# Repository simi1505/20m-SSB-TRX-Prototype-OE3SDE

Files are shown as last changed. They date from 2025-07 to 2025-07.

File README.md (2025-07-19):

# 20m-SSB-TRX-Prototype-OE3SDE
Prototype on a 20m SSB TRX for ham radio by OE3SDE.

## Block Diagram

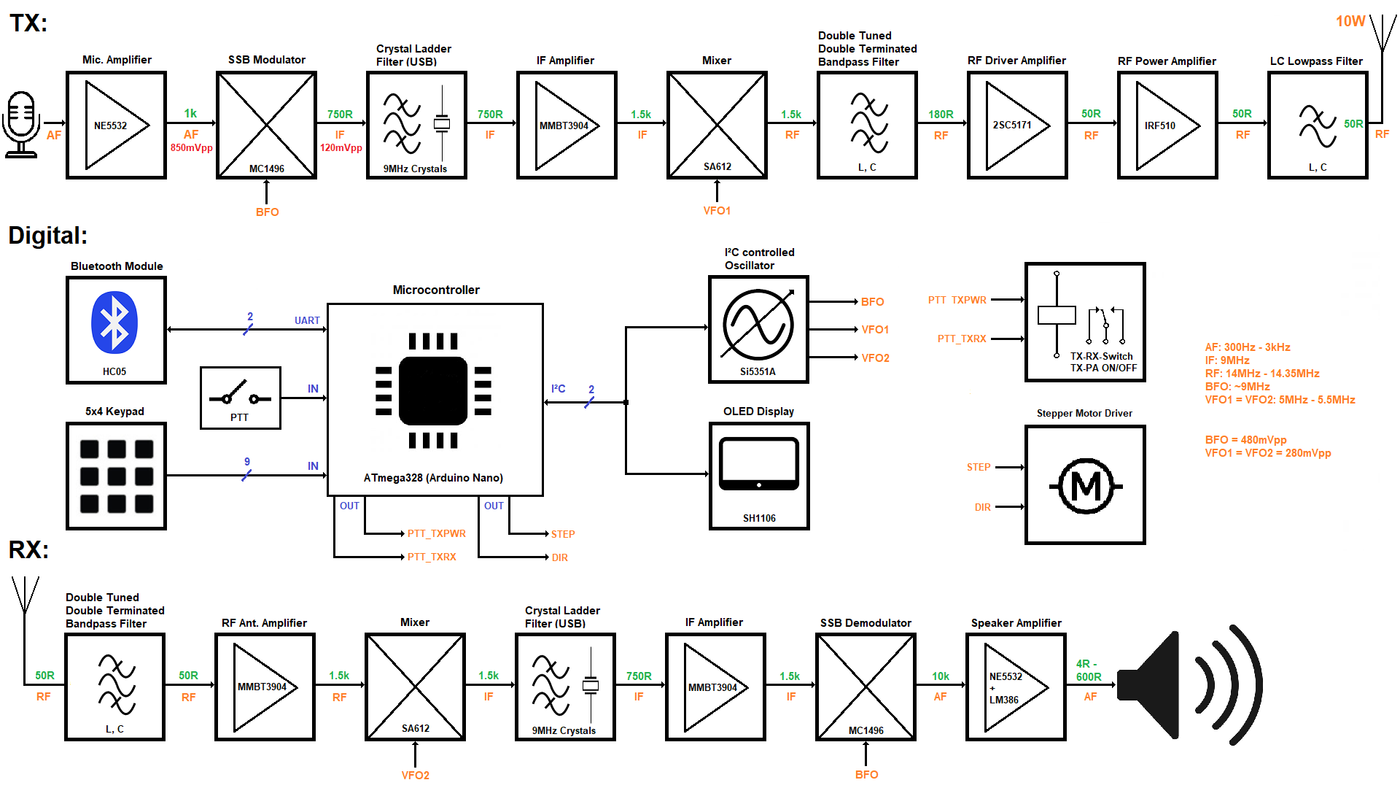
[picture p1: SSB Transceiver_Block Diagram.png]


**Figure 1**: Block diagram of 20m SSB TRX.

## Frequency Spectrum

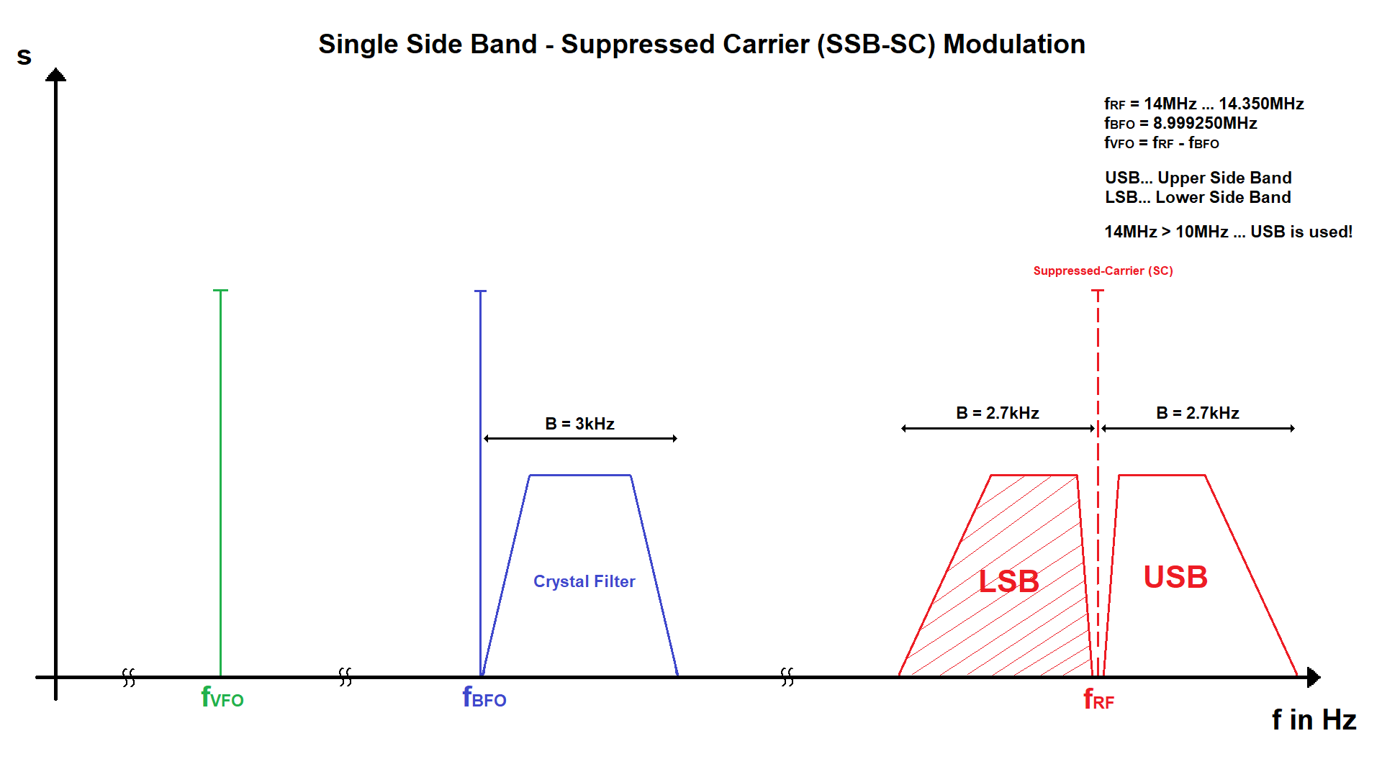
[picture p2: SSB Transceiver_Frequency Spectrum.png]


**Figure 2**: Frequency spectrum of 20m SSB TRX.

## Result

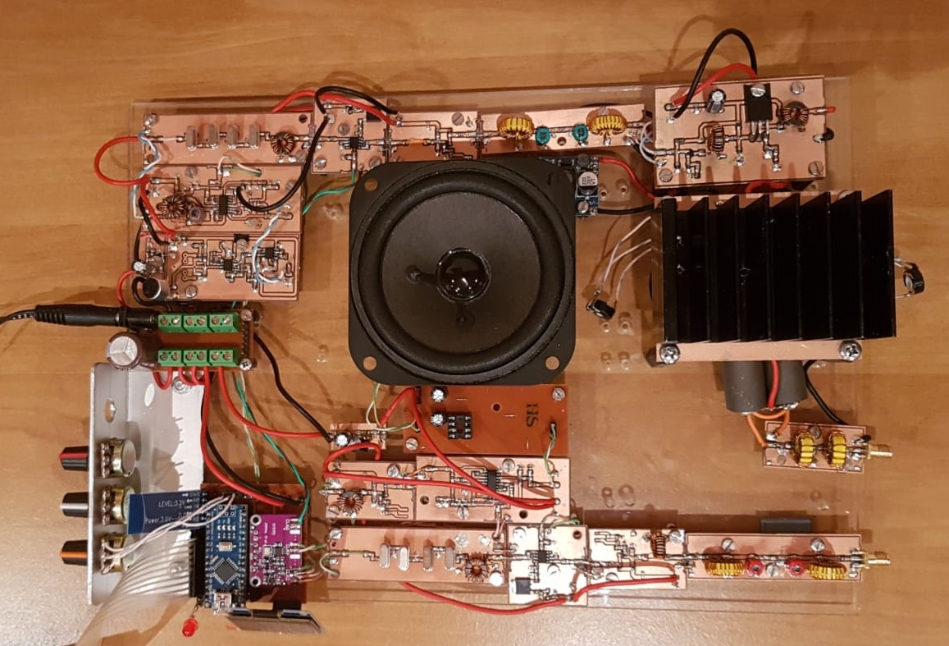
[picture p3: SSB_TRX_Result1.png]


**Figure 3**: Result of 20m SSB TRX prototype.

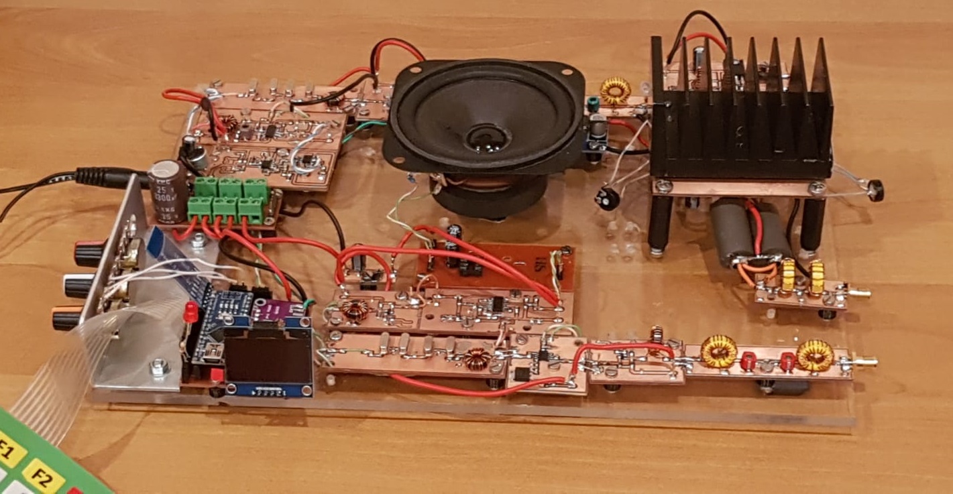
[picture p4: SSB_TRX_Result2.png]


**Figure 4**: Result of 20m SSB TRX prototype.

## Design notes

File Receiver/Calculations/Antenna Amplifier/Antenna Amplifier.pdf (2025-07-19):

Antenna Amplifier | SSB-Transceiver

given: UB≔12V, IC≔0.0033A, βDC≔210 @ 5mA, UBE≔0.6V, f≔14000000Hz
UT≔0.028V @ 5mA, R ≔ | Ohm, | Hz L | 1500 | fT≔300000000

1.) Calculate Bias Voltages:

URC≔0.413 ⋅UB =4.956 V

URE≔0.1 ⋅UB =1.2 V

UCE≔UB −URE −URC =5.844 V

2.) Calculate RE :

RE≔――=

URE
IC

363.636 Ohm = 360Ohm

3.) Calculate IB & I : q

IB≔――=

IC

βDC

0.0000157 A = 15.7uA | Iq≔10 ⋅ IB =0.000157 A = 157uA

4.) Calculate Bias Resistors:

R1≔―――――=

UB −URE −UBE
Iq+IB

59008.264 Ohm = 62k

R2≔――――=

URE +UBE
Iq

11454.545Ohm = 12k

5.) Calculate Z : IN

RE1≔300 Ohm RE2≔100 Ohm variable --> 56...1056Ohm

rE≔――=

UT
IC

8.485 Ohm βAC≔―=

fT
f

21.429 REV≔――――

RE1 ⋅RE2

RE1+RE2

ZIN≔―――――――――=

1

―+ +

1
R1

―1
R2

―――1 ―― βAC ⋅ ⎛⎝rE +REV⎞
⎠

1507.768 Ohm ZIN = 1061...3300Ohm

ZIN = 1.5k @ RE2 = 100Ohm --> VU = 9 (Simulation) --> perfect conditions

RE1 and RE2 are calculated in 9.). | clear ⎛⎝RE1 ,RE2 ,REV⎞ ⎠

Non-Commercial Use Only

Page 1 of 3

6.) Calculate Input Transformer:

ZP≔50 Ohm | ZS≔ZIN =1507.768Ohm
| --> Guideline: 4T:22T @ FT37-43 Toroid Core --> LP≔5.6 ⋅ 10 H @ FT37-43 Toroid Core ⁻⁶ --> LS≔169.4 ⋅ 10 H @ FT37-43 Toroid Core ⁻⁶
ü≔ | =
―

ZS
ZP

5.491

üdB≔10 ⋅log((ü))=7.397 | dB --> 7.397dB gain!
ZS≔ZP ⋅ | =

⎛
⎜

⎝―22
4

⎞
⎟
⎠

2
1512.5 Ohm

Requirement:

XLP≔2 ⋅π⋅ f ⋅LP=492.602 | Ohm > 9 ⋅ZP=450 Ohm --> correct!
XLS≔2 ⋅π⋅ f ⋅LS=14901.202 Ohm > 9 ⋅Z = | Ohm --> correct! IN 13569.912

7.) Calculate ZOUT :

RC≔――=

URC
IC

1501.818 Ohm

8.) Calculate Output Transformer:

No Transformer needed --> input impedance of SA612 equals 1.5k

Page 2 of 3

9.) Calculate VU & REV :

Split up RE in two parallel resistors RE1 & RE2 --> precise VU

REV＝――――

RE1 ⋅RE2

RE1+RE2

VU≔10 :

VU＝―――――→

RC

REV

solve ,REV
150.18181818181818 Ohm = 150Ohm

VU≔5 :

VU＝―――――→

RC

REV

solve ,REV
300.36363636363636 Ohm = 300Ohm

Simulation: RE1＝300Ohm --> IC = 3.3mA, RE2= 56...1056Ohm -->VU = 13...3 @ RL

10.) Calculate Lower Cut-Off Frequency:

CIN≔0.0000001 F = 100nF | COUT≔CIN | CE≔C ⋅ IN 10 | RE1≔200

rBE≔――=

UT
IB

1781.818 Ohm

fGLI≔―――――――=

1
⎛⎝2 ⋅π⋅ ⎛ | ⋅ ⎝ZP ⋅ rBE⎞

⎠ CIN⎞
⎠

17.864 Hz ... Input Cut Off Frequency

fGLO≔――――――――=

1
⎛⎝2 ⋅π⋅ ⎛ | ⋅ ⎝RC +RL

⎞

⎠ COUT⎞
⎠

530.195 Hz ... Output Cut Off Frequency

fGLE≔――――――――――――=

1
⎛⎝2 ⋅π⋅ ⎛ | ⋅ ⎝ZP+rBE +RE1 ⋅ ⎛⎝βDC +1⎞
⎠

⎞
⎠ CE

⎞
⎠

3.615 Hz

... Emitter Cut Off Frequency

The lowest cut off frequency determines the lower cut off frequency of the amplifier!

Page 3 of 3

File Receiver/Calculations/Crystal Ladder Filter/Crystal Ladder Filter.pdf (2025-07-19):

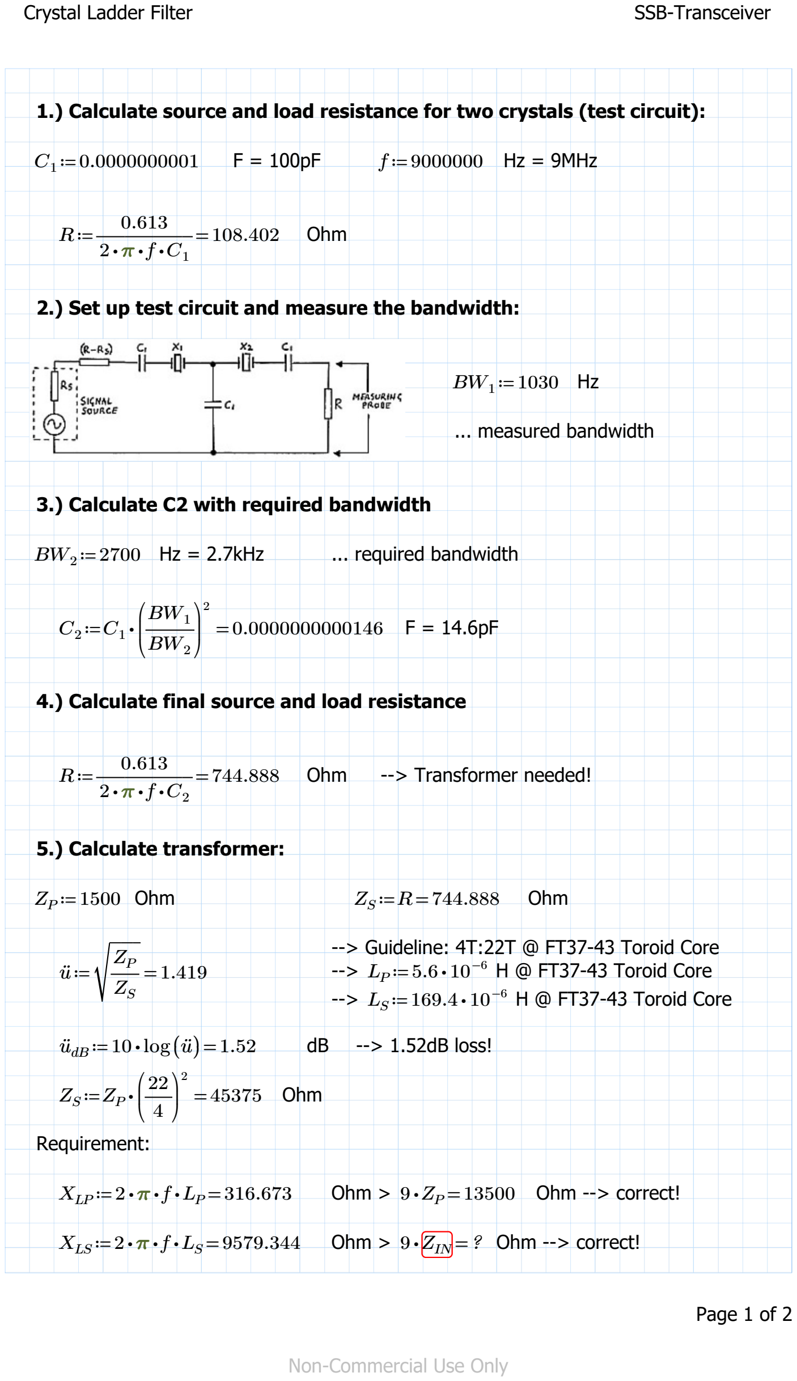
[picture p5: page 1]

Crystal Ladder Filter | SSB-Transceiver

1.) Calculate source and load resistance for two crystals (test circuit):

C1≔0.0000000001 | F = 100pF | f≔9000000 Hz = 9MHz

R≔――――=

0.613
2 ⋅π⋅ f ⋅C1

108.402 Ohm

2.) Set up test circuit and measure the bandwidth:

BW1≔1030 Hz

... measured bandwidth

3.) Calculate C2 with required bandwidth

BW2≔2700 Hz = 2.7kHz ... required bandwidth

C2≔C1

⋅ | =

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
0.0000000000146 F = 14.6pF

4.) Calculate final source and load resistance

R≔――――=

0.613
2 ⋅π⋅ f ⋅C2

744.888 Ohm --> Transformer needed!

5.) Calculate transformer:

ZP≔1500 Ohm | ZS≔R=744.888 | Ohm

--> Guideline: 4T:22T @ FT37-43 Toroid Core --> LP≔5.6 ⋅ 10 H @ FT37-43 Toroid Core ⁻⁶ --> LS≔169.4 ⋅ 10 H @ FT37-43 Toroid Core ⁻⁶

ü≔ =
―

ZP
ZS

1.419

üdB≔10 ⋅log((ü))=1.52 | dB --> 1.52dB loss!
ZS≔ZP ⋅ | =

⎛
⎜

⎝―22
4

⎞
⎟
⎠

2
45375 Ohm

Requirement:

XLP≔2 ⋅π⋅ f ⋅LP=316.673 | Ohm > 9 ⋅ZP=13500 Ohm --> correct!
XLS≔2 ⋅π⋅ f ⋅LS=9579.344 | Ohm > 9 ⋅Z = | Ohm --> correct! IN ?

Non-Commercial Use Only

Page 1 of 2

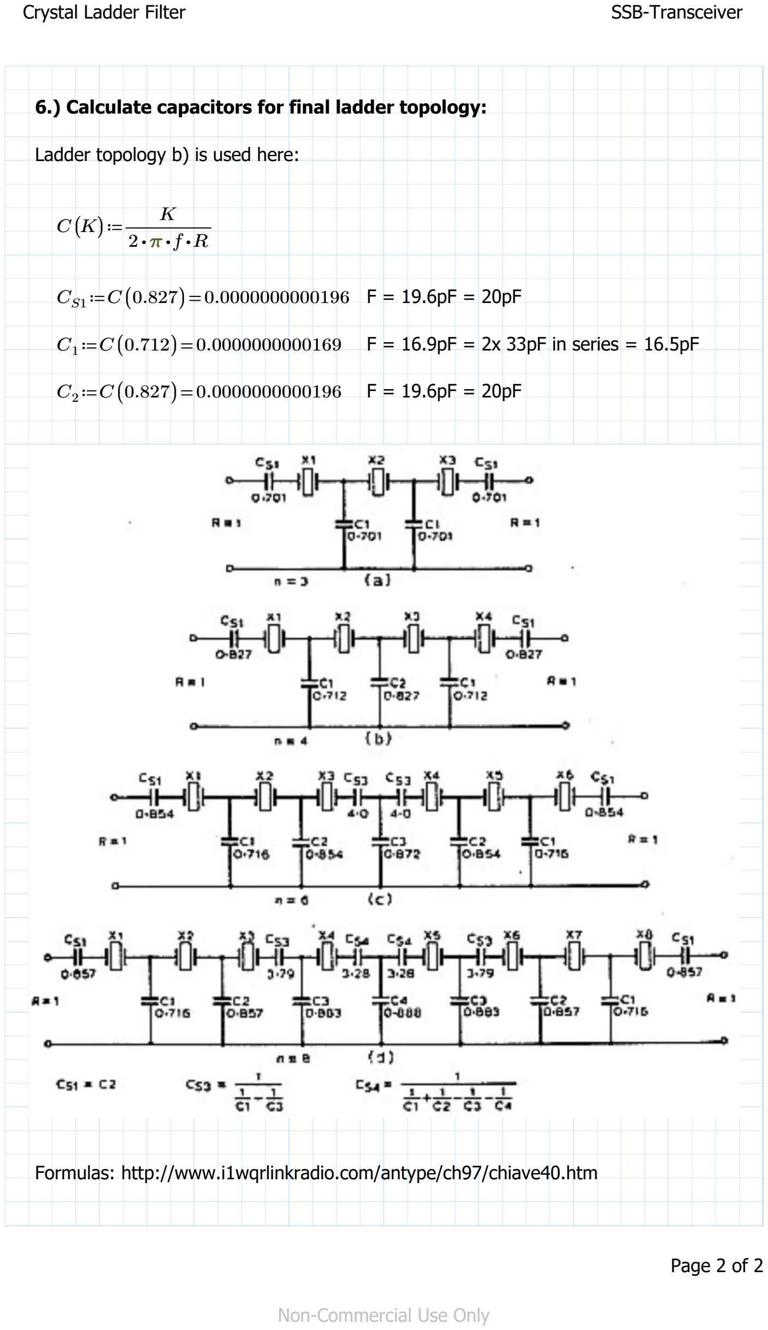
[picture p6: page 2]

Crystal Ladder Filter | SSB-Transceiver

6.) Calculate capacitors for final ladder topology:

Ladder topology b) is used here:

C((K))≔――K ―― 2 ⋅π⋅ f ⋅R

CS1≔C((0.827))=0.0000000000196 F = 19.6pF = 20pF

C1≔C((0.712))=0.0000000000169 F = 16.9pF = 2x 33pF in series = 16.5pF

C2≔C((0.827))=0.0000000000196 F = 19.6pF = 20pF

Formulas: http://www.i1wqrlinkradio.com/antype/ch97/chiave40.htm

Non-Commercial Use Only

Page 2 of 2

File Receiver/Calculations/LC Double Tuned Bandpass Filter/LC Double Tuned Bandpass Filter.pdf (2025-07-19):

LC Double Tuned Bandpass Filters | SSB-Transceiver

Circuit:

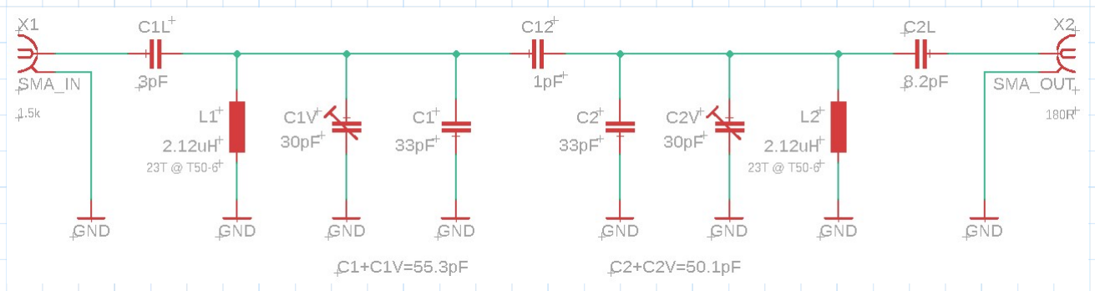
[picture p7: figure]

1.) Define lower and upper cut off frequencies:

f1≔13000000 f2≔15000000

2.) Define inductor core, turns and value (L＝L ＝ ): 1 | L2
L≔2.12 ⋅ 10⁻⁶ | H = 2.12uH --> 23T @ T50-6 Core --> "toroids.info/T50-6.php"
QU≔240 | ... unloaded Q of the resonators

3.) Calculate ω : 0

ω0

... center angular frequency

ω0≔2 ⋅π⋅ f1

⋅f2

=87739907.869 rad/sec

4.) Calculate C : 0

C0

... nodal capacitance

C0≔―――=

1
ω ⋅ 0

### 2 L

0.0000000000613 F = 61.3pF

5.) Calculate Q : L

QL

... loaded filter Q

QL≔―――――=

ω0
2 ⋅π⋅ ⎛⎝f2−f1

⎞
⎠

6.982

Non-Commercial Use Only

Page 1 of 3

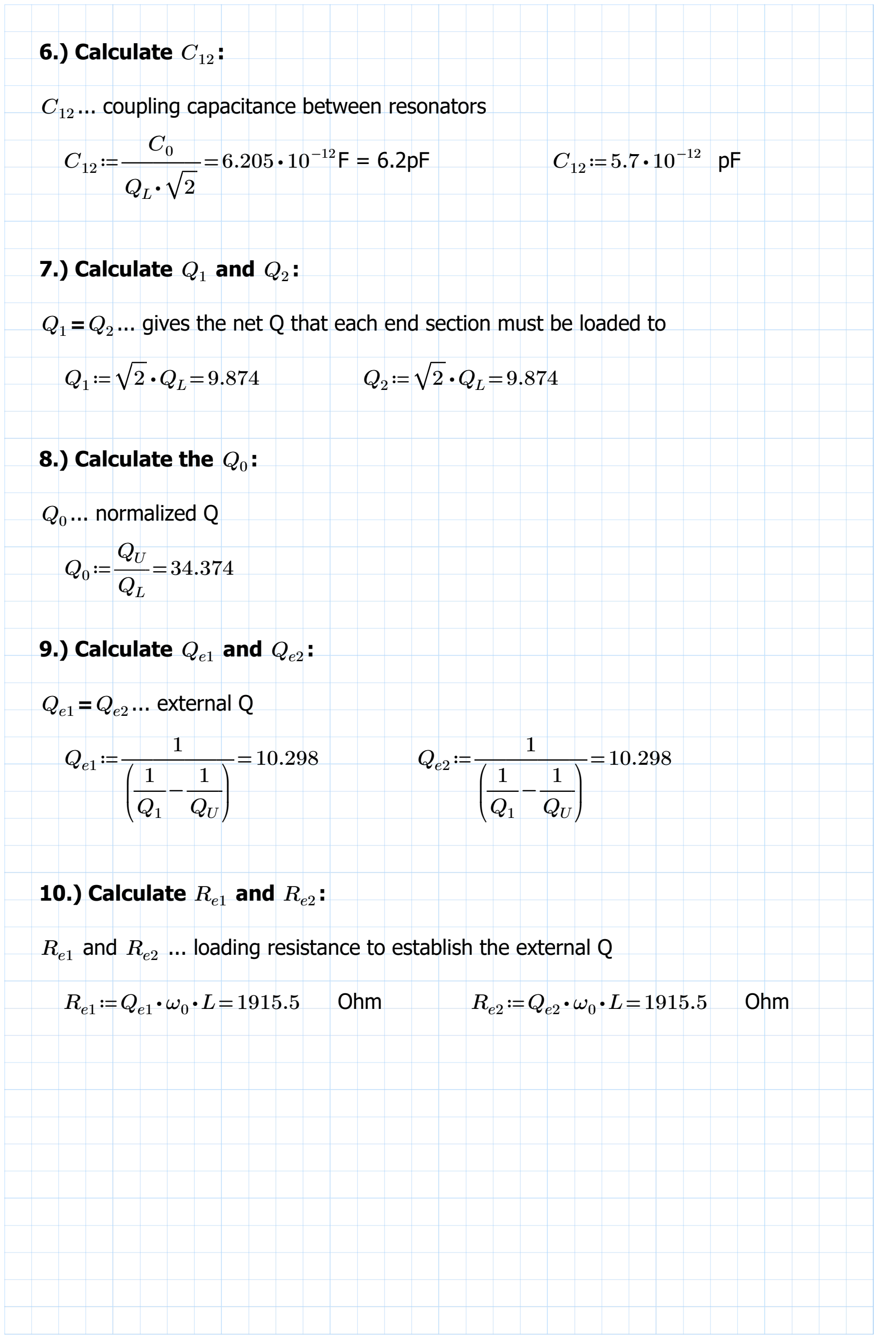
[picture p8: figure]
6.) Calculate C : 12; 7.) Calculate Q and; 8.) Calculate the Q : 0; ... normalized Q; 9.) Calculate Q and; Qe1＝Qe2 ... external Q; 10.) Calculate R and; Ohm

C ... coupling capacitance between resonators 12

6.205 ⋅ 10⁻¹² F = 6.2pF | C12≔5.7 ⋅ 10⁻¹² pF

... gives the net Q that each end section must be loaded to

Re1 and Re2 ... loading resistance to establish the external Q

Page 2 of 3

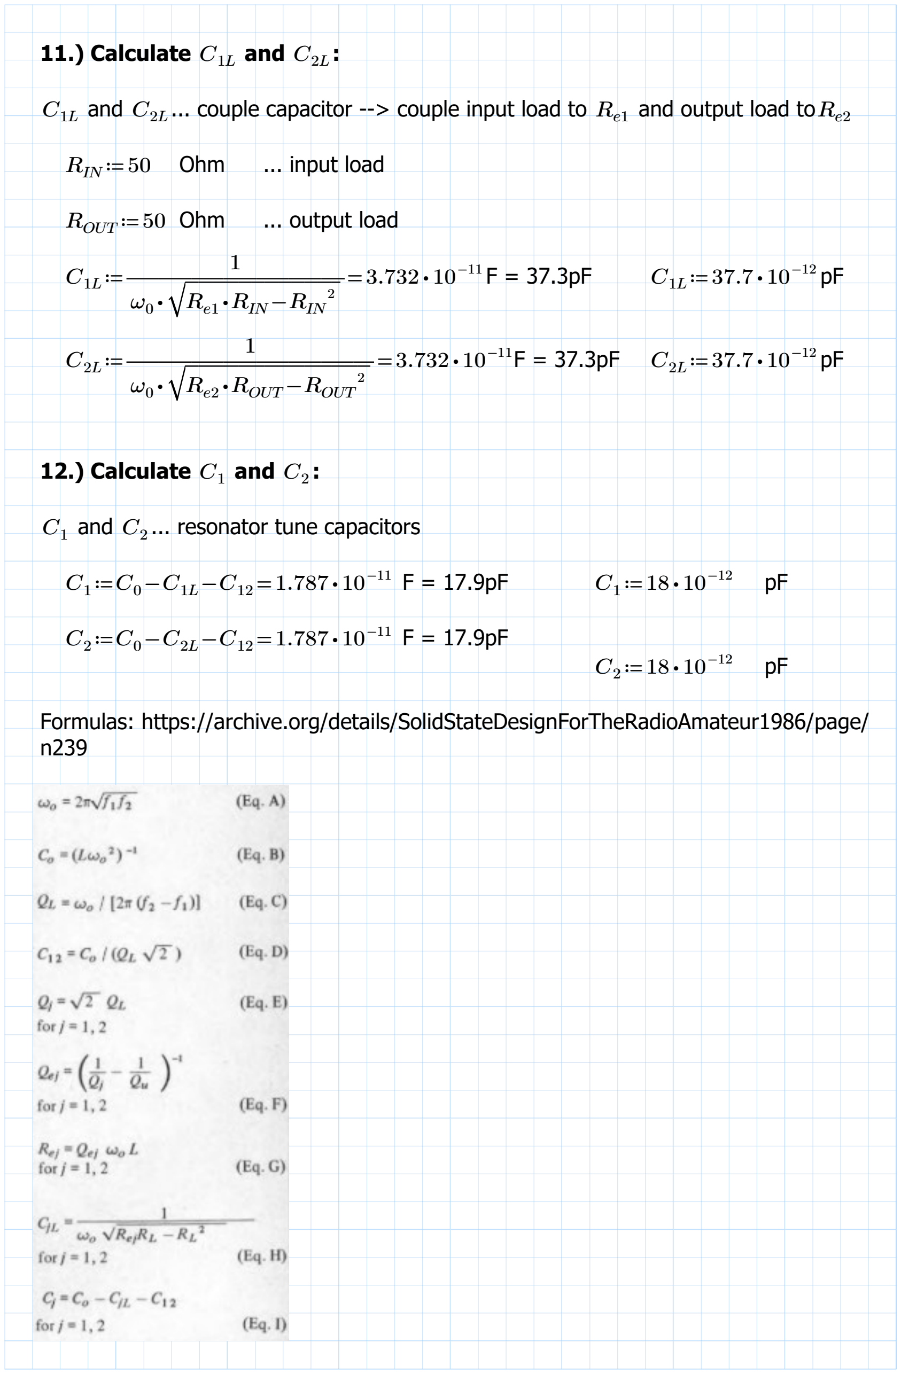
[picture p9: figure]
11.) Calculate C and; RIN≔50 Ohm; ... input load; ROUT≔50 Ohm; ... output load; − R ⋅ e1 RIN RIN; − R ⋅ e2 ROUT ROUT; 3.732 ⋅ 10⁻¹¹F = 37.3pF; 12.) Calculate C and; C and; ... resonator tune capacitors 1; Formulas: https://archive.org/details/SolidStateDesignForTheRadioAmateur1986/page/ n239

C1L and C2L ... couple capacitor --> couple input load to Re1 and output load toRe2

3.732 ⋅ 10⁻¹¹ F = 37.3pF | C1L≔37.7 ⋅ 10⁻¹² pF
C1≔C0−C1L−C12=1.787 ⋅ 10⁻¹¹ F = 17.9pF | C1≔18 ⋅ 10⁻¹² | pF

Page 3 of 3

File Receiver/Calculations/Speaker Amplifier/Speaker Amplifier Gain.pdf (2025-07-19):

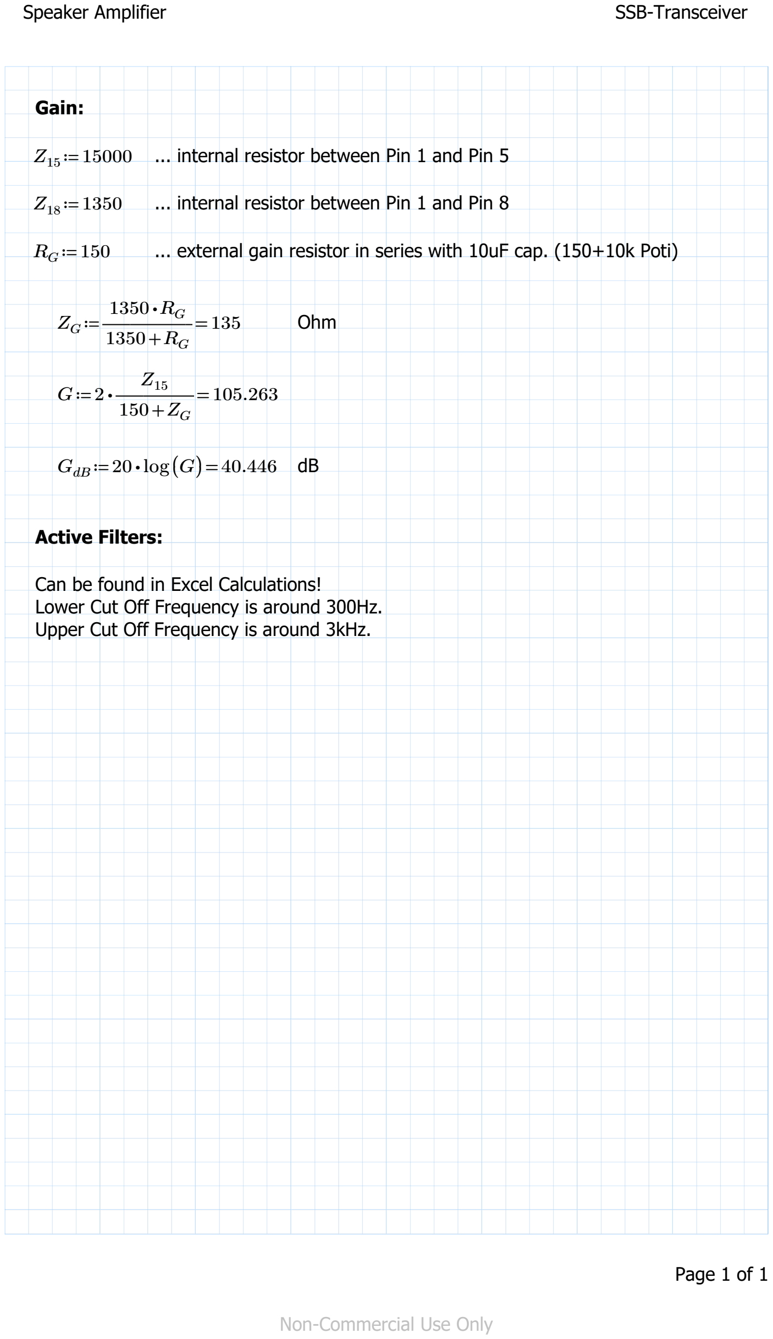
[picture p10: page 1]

Speaker Amplifier | SSB-Transceiver

Gain:

Z15≔15000 ... internal resistor between Pin 1 and Pin 5

Z18≔1350 | ... internal resistor between Pin 1 and Pin 8
RG≔150 | ... external gain resistor in series with 10uF cap. (150+10k Poti)

ZG≔――――=

1350 ⋅RG
1350+RG
| 135 Ohm

G≔2 ⋅―――=

| Z15
150+ZG
| 105.263

GdB≔20 ⋅log((G))=40.446 dB

Active Filters:

Can be found in Excel Calculations!
Lower Cut Off Frequency is around 300Hz. Upper Cut Off Frequency is around 3kHz.

Non-Commercial Use Only

Page 1 of 1

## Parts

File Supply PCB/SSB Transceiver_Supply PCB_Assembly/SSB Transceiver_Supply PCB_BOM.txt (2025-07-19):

Partlist exported from E:/Simon Dorrer/DIY Projekte/Amateurfunkprojekte/SSB Transceiver/Supply PCB/SSB Transceiver_Supply PCB.sch at 14/03/2020 20:48

Qty Value  Device         Package Parts              Description                          MF MPN OC_FARNELL OC_NEWARK POPULARITY SPICEPREFIX
5          AK300/2        AK300/2 X2, X3, X4, X5, X6 CONNECTOR                                   unknown    unknown                         
1   100nF  C-EUC0805K     C0805K  C2                 CAPACITOR, European symbol                                       52         C          
1   12V    AK300/2        AK300/2 X1                 CONNECTOR                                   unknown    unknown                         
1   3300uF CPOL-EUE7.5-16 E7,5-16 C1                 POLARIZED CAPACITOR, European symbol                             4          C          
1   DC-IN  JACK-PLUG1     SPC4078 J1                 DC POWER JACK                               unknown    unknown                         
1   DC-OUT PINHD-1X6      1X06    X7                 PIN HEADER

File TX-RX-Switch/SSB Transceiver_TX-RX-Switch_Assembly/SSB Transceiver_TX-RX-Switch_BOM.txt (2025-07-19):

Partlist exported from E:/Simon Dorrer/DIY Projekte/Amateurfunkprojekte/SSB Transceiver/TX-RX-Switch/SSB Transceiver_TX-RX-Switch.sch at 13/04/2020 13:09

Qty Value       Device                    Package                         Parts Description                                           POPULARITY SPICEPREFIX
1   +12V        PINHD-1X3                 1X03                            JP1   PIN HEADER                                                                  
1   100nF       C-EUC0805K                C0805K                          C1    CAPACITOR, European symbol                            52         C          
1   1N4004      1N4004                    DO41-10                         D1    DIODE                                                                       
1   4.7k        R-EU_R0805                R0805                           R1    RESISTOR, European symbol                             86         R          
1   ANT         SMA-PCB-CON               J502-ND-142-0711-821/826_BOTTOM X3    SMA 50 Ohm End Launch Jack Receptacle - Round Contact                       
1   HK19F-12VDC HK19F-12VDC               HK19F-12VDC                     K1    RELAY                                                                       
1   MMBT3904    MMBT3904LT1-NPN-SOT23-BEC SOT23-BEC                       T1    NPN Transistror                                                             
1   PTT_IN      PINHD-1X3                 1X03                            JP2   PIN HEADER                                                                  
1   RX          SMA-PCB-CON               J502-ND-142-0711-821/826_BOTTOM X1    SMA 50 Ohm End Launch Jack Receptacle - Round Contact                       
1   TX          SMA-PCB-CON               J502-ND-142-0711-821/826_BOTTOM X2    SMA 50 Ohm End Launch Jack Receptacle - Round Contact

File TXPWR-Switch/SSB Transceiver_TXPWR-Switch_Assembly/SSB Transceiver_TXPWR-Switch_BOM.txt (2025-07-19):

Partlist exported from E:/Simon Dorrer/DIY Projekte/Amateurfunkprojekte/SSB Transceiver/TXPWR-Switch/SSB Transceiver_TXPWR-Switch.sch at 13/04/2020 13:48

Qty Value          Device                    Package        Parts Description                POPULARITY SPICEPREFIX
1   +12V           PINHD-1X3                 1X03           JP1   PIN HEADER                                       
1   +12V_S         PINHD-1X3                 1X03           JP3   PIN HEADER                                       
1   100nF          C-EUC0805K                C0805K         C1    CAPACITOR, European symbol 52         C          
1   1N4004         1N4004                    DO41-10        D1    DIODE                                            
1   4.7k           R-EU_R0805                R0805          R1    RESISTOR, European symbol  86         R          
1   MMBT3904       MMBT3904LT1-NPN-SOT23-BEC SOT23-BEC      T1    NPN Transistror                                  
1   PTT_IN         PINHD-1X3                 1X03           JP2   PIN HEADER                                       
1   SRD-12VDC-SL-C SRD-12VDC-SL-C            SRD-12VDC-SL-C K1    RELAY

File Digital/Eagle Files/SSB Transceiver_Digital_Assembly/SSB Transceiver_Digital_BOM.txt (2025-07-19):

Partlist exported from E:/Simon Dorrer/DIY Projekte/Amateurfunkprojekte/SSB Transceiver/Digital/Eagle Files/SSB Transceiver_Digital.sch at 10/04/2020 19:08

Qty Value        Device       Package      Parts Description                MF MPN OC_FARNELL OC_NEWARK POPULARITY SPICEPREFIX
1   100nF        C-EUC0805K   C0805K       C1    CAPACITOR, European symbol                             52         C          
1   12V-IN       JACK-PLUG1   SPC4078      J1    DC POWER JACK                     unknown    unknown                         
1   2k           R-EU_R0805   R0805        R1    RESISTOR, European symbol                              86         R          
1   4.7k         R-EU_R0805   R0805        R2    RESISTOR, European symbol                              86         R          
1   470R         R-EU_R0805   R0805        R3    RESISTOR, European symbol                              86         R          
1   Arduino Nano ARDUINO_NANO ARDUINO_NANO U1    Arduino Nano V3.0                                                            
1   Display      PINHD-1X4    1X04         JP6   PIN HEADER                                                                   
1   HC-05        PINHD-1X6    1X06         JP1   PIN HEADER                                                                   
1   Keyboard     PINHD-1X9    1X09         JP5   PIN HEADER                                                                   
1   POTI_F       PINHD-1X3    1X03         JP7   PIN HEADER                                                                   
1   PTT_I        PINHD-1X2    1X02         JP2   PIN HEADER                                                                   
1   PTT_O        PINHD-1X3    1X03         JP4   PIN HEADER                                                                   
1   SI5351       SI5351       1X07         U2                                                                                 
1   Stepper      PINHD-1X4    1X04         JP8   PIN HEADER                                                                   
1   TX_L         PINHD-1X2    1X02         JP3   PIN HEADER

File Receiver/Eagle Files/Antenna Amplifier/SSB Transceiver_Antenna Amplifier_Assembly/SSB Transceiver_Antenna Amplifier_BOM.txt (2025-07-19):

Partlist exported from E:/Simon Dorrer/DIY Projekte/Amateurfunkprojekte/SSB Transceiver/Receiver/Eagle Files/Antenna Amplifier/SSB Transceiver_Antenna Amplifier.sch at 15/01/2020 23:03

Qty Value          Device                      Package                  Parts      Description                                           MF                 MPN          OC_FARNELL OC_NEWARK POPULARITY SPICEPREFIX
1   1.5k           R-EU_R0805                  R0805                    R3         RESISTOR, European symbol                                                                                  86         R          
3   100nF          C-EUC0805                   C0805                    C1, C2, C4 CAPACITOR, European symbol                                                                                 88         C          
1   12V            PINHD-1X2                   1X02                     JP1        PIN HEADER                                                                                                                       
1   12k            R-EU_R0805                  R0805                    R2         RESISTOR, European symbol                                                                                  86         R          
1   1k             TRIM_EU-3223G               3223G                    R6         POTENTIOMETER                                                                                                                    
1   1uF            C-EUC0805                   C0805                    C3         CAPACITOR, European symbol                                                                                 88         C          
1   300R           R-EU_R0805                  R0805                    R4         RESISTOR, European symbol                                                                                  86         R          
1   56R            R-EU_R0805                  R0805                    R5         RESISTOR, European symbol                                                                                  86         R          
1   62k            R-EU_R0805                  R0805                    R1         RESISTOR, European symbol                                                                                  86         R          
1   ANT. IN        SMA-PCB-CON142-0711-821/826 J502-ND-142-0711-821/826 X1         SMA 50 Ohm End Launch Jack Receptacle - Round Contact JOHNSON COMPONENTS 142-0711-821 1019328    16F3627                         
1   FT37-43        FT37-43                     FT37-43SMD               T1                                                                                                                                          
1   MMBT3904       MMBT3904LT1-NPN-SOT23-BEC   SOT23-BEC                T2         NPN Transistror                                                                                                                  
1   To SA612 Mixer SMA-PCB-CON142-0711-821/826 J502-ND-142-0711-821/826 X2         SMA 50 Ohm End Launch Jack Receptacle - Round Contact JOHNSON COMPONENTS 142-0711-821 1019328    16F3627

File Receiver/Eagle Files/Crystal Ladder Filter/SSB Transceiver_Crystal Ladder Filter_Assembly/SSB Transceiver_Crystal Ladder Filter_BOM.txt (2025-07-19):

Partlist exported from E:/Simon Dorrer/DIY Projekte/Amateurfunkprojekte/SSB Transceiver/Transmitter/Eagle Files/Crystal Ladder Filter/SSB Transceiver_Crystal Ladder Filter.sch at 13/01/2020 09:06

Qty Value   Device               Package                  Parts          Description                                           MF                 MPN          OC_FARNELL OC_NEWARK POPULARITY SPICEPREFIX
2   16.5pF  C-EUC0805            C0805                    C2, C4         CAPACITOR, European symbol                                                                                 88         C          
3   20pF    C-EUC0805            C0805                    C1, C3, C5     CAPACITOR, European symbol                                                                                 88         C          
4   9MHz    CRYSTALHC49S         HC49/S                   Q1, Q2, Q3, Q4 CRYSTAL                                                                               1667008    unknown                         
2   FT37-43 FT37-43              FT37-43SMD               T1, T2                                                                                                                                          
1   SMA_IN  SMA-142-0711-821/826 J502-ND-142-0711-821/826 X1             SMA 50 Ohm End Launch Jack Receptacle - Round Contact JOHNSON COMPONENTS 142-0711-821 1019328    16F3627                         
1   SMA_OUT SMA-142-0711-821/826 J502-ND-142-0711-821/826 X2             SMA 50 Ohm End Launch Jack Receptacle - Round Contact JOHNSON COMPONENTS 142-0711-821 1019328    16F3627

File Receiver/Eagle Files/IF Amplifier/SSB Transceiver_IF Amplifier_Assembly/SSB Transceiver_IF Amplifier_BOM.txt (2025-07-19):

Partlist exported from E:/Simon Dorrer/DIY Projekte/Amateurfunkprojekte/SSB Transceiver/Receiver/Eagle Files/IF Amplifier/SSB Transceiver_IF Amplifier.sch at 15/01/2020 23:15

Qty Value            Device                      Package                  Parts      Description                                           MF                 MPN          OC_FARNELL OC_NEWARK POPULARITY SPICEPREFIX
1   1.5k             R-EU_R0805                  R0805                    R3         RESISTOR, European symbol                                                                                  86         R          
3   100nF            C-EUC0805                   C0805                    C1, C2, C4 CAPACITOR, European symbol                                                                                 88         C          
1   12V              PINHD-1X2                   1X02                     JP1        PIN HEADER                                                                                                                       
1   12k              R-EU_R0805                  R0805                    R2         RESISTOR, European symbol                                                                                  86         R          
1   1k               TRIM_EU-3223G               3223G                    R6         POTENTIOMETER                                                                                                                    
1   1uF              C-EUC0805                   C0805                    C3         CAPACITOR, European symbol                                                                                 88         C          
1   300R             R-EU_R0805                  R0805                    R4         RESISTOR, European symbol                                                                                  86         R          
1   56R              R-EU_R0805                  R0805                    R5         RESISTOR, European symbol                                                                                  86         R          
1   62k              R-EU_R0805                  R0805                    R1         RESISTOR, European symbol                                                                                  86         R          
1   FT37-43          FT37-43                     FT37-43SMD               T1                                                                                                                                          
1   From Crystal     SMA-PCB-CON142-0711-821/826 J502-ND-142-0711-821/826 X1         SMA 50 Ohm End Launch Jack Receptacle - Round Contact JOHNSON COMPONENTS 142-0711-821 1019328    16F3627                         
1   MMBT3904         MMBT3904LT1-NPN-SOT23-BEC   SOT23-BEC                T2         NPN Transistror                                                                                                                  
1   To MC1496 Demod. SMA-PCB-CON142-0711-821/826 J502-ND-142-0711-821/826 X2         SMA 50 Ohm End Launch Jack Receptacle - Round Contact JOHNSON COMPONENTS 142-0711-821 1019328    16F3627

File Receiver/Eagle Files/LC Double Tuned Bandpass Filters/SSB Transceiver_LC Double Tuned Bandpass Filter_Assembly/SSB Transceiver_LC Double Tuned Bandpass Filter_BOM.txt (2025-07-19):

Partlist exported from E:/Simon Dorrer/DIY Projekte/Amateurfunkprojekte/SSB Transceiver/Receiver/Eagle Files/LC Double Tuned Bandpass Filters/SSB Transceiver_LC Double Tuned Bandpass Filter.sch at 11/02/2020 19:55

Qty Value   Device               Package                  Parts    Description                                           MF                 MPN          OC_FARNELL OC_NEWARK POPULARITY SPICEPREFIX
2   10pF    C-EUC0805            C0805                    C1, C2   CAPACITOR, European symbol                                                                                 88         C          
2   2.12uH  T50-6                T50-6SMD                 L1, L2                                                                                                                                    
2   20pF    VARIABLECAP          VARIABLECAP-SMD          C1V, C2V                                                                                                                                  
2   37.7pF  C-EUC0805            C0805                    C1L, C2L CAPACITOR, European symbol                                                                                 88         C          
1   5.7pF   C-EUC0805            C0805                    C12      CAPACITOR, European symbol                                                                                 88         C          
1   SMA_IN  SMA-142-0711-821/826 J502-ND-142-0711-821/826 X1       SMA 50 Ohm End Launch Jack Receptacle - Round Contact JOHNSON COMPONENTS 142-0711-821 1019328    16F3627                         
1   SMA_OUT SMA-142-0711-821/826 J502-ND-142-0711-821/826 X2       SMA 50 Ohm End Launch Jack Receptacle - Round Contact JOHNSON COMPONENTS 142-0711-821 1019328    16F3627

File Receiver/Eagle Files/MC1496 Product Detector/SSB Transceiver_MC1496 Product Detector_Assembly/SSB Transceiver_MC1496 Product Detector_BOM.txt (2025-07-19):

Partlist exported from E:/Simon Dorrer/DIY Projekte/Amateurfunkprojekte/SSB Transceiver/Receiver/Eagle Files/MC1496 Product Detector/SSB Transceiver_MC1496 Product Detector.sch at 12/01/2020 20:46

Qty Value      Device               Package                  Parts               Description                                           AVAILABILITY DESCRIPTION                                     MF                 MP         MPN          OC_FARNELL OC_NEWARK PACKAGE                  POPULARITY PRICE SPICEPREFIX
1   1.2k       R-EU_R0805           R0805                    R7                  RESISTOR, European symbol                                                                                                                                                                                   86               R          
1   100R       R-EU_R0805           R0805                    R10                 RESISTOR, European symbol                                                                                                                                                                                   86               R          
5   100nF      C-EUC0805            C0805                    C2, C4, C5, C6, C10 CAPACITOR, European symbol                                                                                                                                                                                  88               C          
1   10k        R-EU_R0805           R0805                    R8                  RESISTOR, European symbol                                                                                                                                                                                   86               R          
1   10k        TRIM_EU-3223G        3223G                    R1                  POTENTIOMETER                                                                                                                                                                                                                           
1   12V        AK300/2              AK300/2                  X3                  CONNECTOR                                                                                                                                                     unknown    unknown                                                        
4   1k         R-EU_R0805           R0805                    R2, R3, R5, R12     RESISTOR, European symbol                                                                                                                                                                                   86               R          
1   1nF        C-EUC0805            C0805                    C1                  CAPACITOR, European symbol                                                                                                                                                                                  88               C          
3   1uF        C-EUC0805            C0805                    C7, C12, C13        CAPACITOR, European symbol                                                                                                                                                                                  88               C          
1   220nF      C-EUC0805            C0805                    C3                  CAPACITOR, European symbol                                                                                                                                                                                  88               C          
2   3k         R-EU_R0805           R0805                    R9, R11             RESISTOR, European symbol                                                                                                                                                                                   86               R          
3   4.7nF      C-EUC0805            C0805                    C8, C9, C11         CAPACITOR, European symbol                                                                                                                                                                                  88               C          
1   51R        R-EU_R0805           R0805                    R6                  RESISTOR, European symbol                                                                                                                                                                                   86               R          
1   820        R-EU_R0805           R0805                    R4                  RESISTOR, European symbol                                                                                                                                                                                   86               R          
1   AF-OUT     AK300/2              AK300/2                  X4                  CONNECTOR                                                                                                                                                     unknown    unknown                                                        
1   MC1496DR2G MC1496DR2G           SOIC127P600X175-14N      U1                                                                        Unavailable   RF IC Modulator/Demodulator FM 300MHz 14-SOIC  ON Semiconductor   MC1496DR2G                                   SOIC-14 ON Semiconductor            None             
1   OSC. IN    SMA-142-0711-821/826 J502-ND-142-0711-821/826 X2                  SMA 50 Ohm End Launch Jack Receptacle - Round Contact                                                              JOHNSON COMPONENTS            142-0711-821 1019328    16F3627                                                        
1   SSB_IN     AK300/2              AK300/2                  X1                  CONNECTOR                                                                                                                                                     unknown    unknown

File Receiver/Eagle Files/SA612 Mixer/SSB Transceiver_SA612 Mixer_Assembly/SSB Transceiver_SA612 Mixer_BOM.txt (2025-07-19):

Partlist exported from E:/Simon Dorrer/DIY Projekte/Amateurfunkprojekte/SSB Transceiver/Transmitter/Eagle Files/SA612 Mixer/SSB Transceiver_SA612 Mixer.sch at 12/01/2020 17:16

Qty Value       Device               Package                  Parts              Description                                           MF                 MPN          OC_FARNELL OC_NEWARK POPULARITY SPICEPREFIX
5   100nF       C-EUC0805            C0805                    C1, C4, C5, C7, C8 CAPACITOR, European symbol                                                                                 88         C          
1   10nF        C-EUC0805            C0805                    C6                 CAPACITOR, European symbol                                                                                 88         C          
1   12V         AK300/2              AK300/2                  X1                 CONNECTOR                                                                             unknown    unknown                         
1   1N4148      DIODE-SOD323-W       SOD323-W                 D1                 DIODE                                                                                                                            
1   1nF         C-EUC0805            C0805                    C3                 CAPACITOR, European symbol                                                                                 88         C          
1   330nF       C-EUC0805            C0805                    C2                 CAPACITOR, European symbol                                                                                 88         C          
1   51R         R-EU_M0805           M0805                    R1                 RESISTOR, European symbol                                                                                  45         R          
1   7805DT      7805DT               TO252                    U1                 Positive VOLTAGE REGULATOR                                                                                                       
1   IF IN/OUT   SMA-142-0711-821/826 J502-ND-142-0711-821/826 X3                 SMA 50 Ohm End Launch Jack Receptacle - Round Contact JOHNSON COMPONENTS 142-0711-821 1019328    16F3627                         
1   OSC. IN/OUT SMA-142-0711-821/826 J502-ND-142-0711-821/826 X2                 SMA 50 Ohm End Launch Jack Receptacle - Round Contact JOHNSON COMPONENTS 142-0711-821 1019328    16F3627                         
1   RF IN/OUT   SMA-142-0711-821/826 J502-ND-142-0711-821/826 X4                 SMA 50 Ohm End Launch Jack Receptacle - Round Contact JOHNSON COMPONENTS 142-0711-821 1019328    16F3627                         
1   SA612AD     SA612AD              SO08                     U2                 Double-balanced mixer and oscillator NE612/SA612

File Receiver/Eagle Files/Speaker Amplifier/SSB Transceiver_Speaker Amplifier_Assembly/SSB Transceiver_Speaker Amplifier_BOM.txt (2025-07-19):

Partlist exported from E:/Simon Dorrer/DIY Projekte/Amateurfunkprojekte/SSB Transceiver/Receiver/Eagle Files/Speaker Amplifier/SSB Transceiver_Speaker Amplifier.sch at 11/03/2020 00:20

Qty Value    Device        Package Parts                Description                          MF MPN OC_FARNELL OC_NEWARK POPULARITY SPICEPREFIX
1   1.2nF    C-EUC0805     C0805   C5                   CAPACITOR, European symbol                                       88         C          
5   100nF    C-EUC0805     C0805   C1, C4, C6, C10, C14 CAPACITOR, European symbol                                       88         C          
2   100uF    CPOL-EUE2.5-6 E2,5-6  C11, C15             POLARIZED CAPACITOR, European symbol                             26         C          
1   10R      R-EU_R0805    R0805   R13                  RESISTOR, European symbol                                        86         R          
3   10k      R-EU_R0805    R0805   R7, R8, R12          RESISTOR, European symbol                                        86         R          
1   10k      TRIM_EU-3223G 3223G   R11                  POTENTIOMETER                                                                          
1   10nF     C-EUC0805     C0805   C8                   CAPACITOR, European symbol                                       88         C          
3   10uF     C-EUC0805     C0805   C9, C12, C13         CAPACITOR, European symbol                                       88         C          
1   12V      AK300/2       AK300/2 X2                   CONNECTOR                                   unknown    unknown                         
2   12nF     C-EUC0805     C0805   C2, C3               CAPACITOR, European symbol                                       88         C          
1   150R     R-EU_R0805    R0805   R10                  RESISTOR, European symbol                                        86         R          
1   15k      R-EU_R0805    R0805   R2                   RESISTOR, European symbol                                        86         R          
1   1k       R-EU_R0805    R0805   R1                   RESISTOR, European symbol                                        86         R          
1   1nF      C-EUC0805     C0805   C7                   CAPACITOR, European symbol                                       88         C          
1   24k      R-EU_R0805    R0805   R5                   RESISTOR, European symbol                                        86         R          
1   2k       R-EU_R0805    R0805   R9                   RESISTOR, European symbol                                        86         R          
1   43k      R-EU_R0805    R0805   R3                   RESISTOR, European symbol                                        86         R          
1   47k      R-EU_R0805    R0805   R6                   RESISTOR, European symbol                                        86         R          
1   56k      R-EU_R0805    R0805   R4                   RESISTOR, European symbol                                        86         R          
1   LM386N-4 LM386N-4      DIL08   U2                   Low Voltage Audio Power Amplifier                                                      
1   NE5532D  NE5532D       SO08    U1                   AUDIO AMPLIFIER                                                                        
1   NF-IN    AK300/2       AK300/2 X1                   CONNECTOR                                   unknown    unknown                         
1   NF-IN    PINHD-1X1     1X01    JP1                  PIN HEADER                                                                             
1   NF-OUT   AK300/2       AK300/2 X3                   CONNECTOR                                   unknown    unknown

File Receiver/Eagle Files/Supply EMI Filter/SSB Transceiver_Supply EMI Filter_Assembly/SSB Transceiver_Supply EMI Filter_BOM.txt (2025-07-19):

Partlist exported from E:/Simon Dorrer/DIY Projekte/Amateurfunkprojekte/SSB Transceiver/Transmitter/Eagle Files/Supply EMI Filter/SSB Transceiver_Supply EMI Filter.sch at 07/01/2020 21:00

Qty Value          Device              Package Parts  Description                          POPULARITY PROD_ID    SPICEPREFIX VALUE           
1   100uF          CPOL-EUE2.5-7       E2,5-7  C1     POLARIZED CAPACITOR, European symbol 17                    C                           
1   10R            R-EU_R0805          R0805   R1     RESISTOR, European symbol            86                    R                           
2   10nF           C-EUC0805           C0805   C2, C4 CAPACITOR, European symbol           88                    C                           
1   10uF           C-EUC0805           C0805   C3     CAPACITOR, European symbol           88                    C                           
1   12V            PINHD-1X2           1X02    JP1    PIN HEADER                                                                             
1   12V_filtered   PINHD-1X2           1X02    JP2    PIN HEADER                                                                             
1   BLM21SP102SH1D INDUCTOR-0805-3.3UH 0805    L1     Inductors                                       NDUC-13076             3.3µH/±20%/450mA

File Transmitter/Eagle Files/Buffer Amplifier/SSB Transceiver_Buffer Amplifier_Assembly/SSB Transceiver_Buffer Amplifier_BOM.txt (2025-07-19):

Partlist exported from E:/Simon Dorrer/DIY Projekte/Amateurfunkprojekte/SSB Transceiver/Transmitter/Eagle Files/Buffer Amplifier/SSB Transceiver_Buffer Amplifier.sch at 01/05/2020 20:04

Qty Value          Device                      Package                  Parts      Description                                           MF                 MPN          OC_FARNELL OC_NEWARK POPULARITY SPICEPREFIX
3   100nF          C-EUC0805                   C0805                    C1, C2, C3 CAPACITOR, European symbol                                                                                 88         C          
1   12V            PINHD-1X2                   1X02                     JP1        PIN HEADER                                                                                                                       
1   165R           R-EU_R0805                  R0805                    R3         RESISTOR, European symbol                                                                                  86         R          
1   2.7k           R-EU_R0805                  R0805                    R1         RESISTOR, European symbol                                                                                  86         R          
1   3.9k           R-EU_R0805                  R0805                    R2         RESISTOR, European symbol                                                                                  86         R          
1   From BPF       SMA-PCB-CON142-0711-821/826 J502-ND-142-0711-821/826 X1         SMA 50 Ohm End Launch Jack Receptacle - Round Contact JOHNSON COMPONENTS 142-0711-821 1019328    16F3627                         
1   MMBT3904       MMBT3904LT1-NPN-SOT23-BEC   SOT23-BEC                T1         NPN Transistror                                                                                                                  
1   To Driver Amp. SMA-PCB-CON142-0711-821/826 J502-ND-142-0711-821/826 X2         SMA 50 Ohm End Launch Jack Receptacle - Round Contact JOHNSON COMPONENTS 142-0711-821 1019328    16F3627

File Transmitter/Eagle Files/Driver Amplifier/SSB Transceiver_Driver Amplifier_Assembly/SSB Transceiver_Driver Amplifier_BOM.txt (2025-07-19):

Partlist exported from E:/Simon Dorrer/DIY Projekte/Amateurfunkprojekte/SSB Transceiver/Transmitter/Eagle Files/Driver Amplifier/SSB Transceiver_Driver Amplifier.sch at 08/02/2020 14:05

Qty Value    Device                      Package                  Parts              Description                                                MF                 MPN          OC_FARNELL OC_NEWARK POPULARITY SPICEPREFIX
5   100nF    C-EUC0805                   C0805                    C1, C3, C4, C5, C6 CAPACITOR, European symbol                                                                                      88         C          
1   100uF    C-EUC0805                   C0805                    C2                 CAPACITOR, European symbol                                                                                      88         C          
1   12V      AK300/2                     AK300/2                  X3                 CONNECTOR                                                                                  unknown    unknown                         
1   15k      R-EU_R0805                  R0805                    R1                 RESISTOR, European symbol                                                                                       86         R          
1   1k       R-EU_R0805                  R0805                    R5                 RESISTOR, European symbol                                                                                       86         R          
1   220R     R-EU_R0805                  R0805                    R6                 RESISTOR, European symbol                                                                                       86         R          
1   2SC5171  TIP31B                      TO220                    Q2                 NPN Transistor  Medium Power Linear Switching Applications                                                                            
1   3.3R     R-EU_R0805                  R0805                    R7                 RESISTOR, European symbol                                                                                       86         R          
1   3.3k     R-EU_R0805                  R0805                    R2                 RESISTOR, European symbol                                                                                       86         R          
1   43R      R-EU_R0805                  R0805                    R8                 RESISTOR, European symbol                                                                                       86         R          
1   56R      R-EU_R0805                  R0805                    R3                 RESISTOR, European symbol                                                                                       86         R          
1   8.5R     R-EU_R0805                  R0805                    R4                 RESISTOR, European symbol                                                                                       86         R          
2   FT37-43  FT37-43                     FT37-43SMD               T1, T2                                                                                                                                                   
1   MMBT3904 MMBT3904LT1-NPN-SOT23-BEC   SOT23-BEC                Q1                 NPN Transistror                                                                                                                       
1   SMA-IN   SMA-PCB-CON142-0711-821/826 J502-ND-142-0711-821/826 X1                 SMA 50 Ohm End Launch Jack Receptacle - Round Contact      JOHNSON COMPONENTS 142-0711-821 1019328    16F3627                         
1   SMA-OUT  SMA-PCB-CON142-0711-821/826 J502-ND-142-0711-821/826 X2                 SMA 50 Ohm End Launch Jack Receptacle - Round Contact      JOHNSON COMPONENTS 142-0711-821 1019328    16F3627

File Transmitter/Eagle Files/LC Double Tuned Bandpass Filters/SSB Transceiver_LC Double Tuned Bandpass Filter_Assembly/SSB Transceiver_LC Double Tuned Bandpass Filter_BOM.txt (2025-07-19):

Partlist exported from E:/Simon Dorrer/DIY Projekte/Amateurfunkprojekte/SSB Transceiver/Transmitter/Eagle Files/LC Double Tuned Bandpass Filters/SSB Transceiver_LC Double Tuned Bandpass Filter.sch at 08/02/2020 17:09

Qty Value   Device               Package                  Parts    Description                                           MF                 MPN          OC_FARNELL OC_NEWARK POPULARITY SPICEPREFIX
1   1pF     C-EUC0805            C0805                    C12      CAPACITOR, European symbol                                                                                 88         C          
2   2.12uH  T50-6                T50-6SMD                 L1, L2                                                                                                                                    
2   30pF    VARIABLECAP          VARIABLECAP-SMD          C1V, C2V                                                                                                                                  
2   33pF    C-EUC0805            C0805                    C1, C2   CAPACITOR, European symbol                                                                                 88         C          
1   3pF     C-EUC0805            C0805                    C1L      CAPACITOR, European symbol                                                                                 88         C          
1   8.2pF   C-EUC0805            C0805                    C2L      CAPACITOR, European symbol                                                                                 88         C          
1   SMA_IN  SMA-142-0711-821/826 J502-ND-142-0711-821/826 X1       SMA 50 Ohm End Launch Jack Receptacle - Round Contact JOHNSON COMPONENTS 142-0711-821 1019328    16F3627                         
1   SMA_OUT SMA-142-0711-821/826 J502-ND-142-0711-821/826 X2       SMA 50 Ohm End Launch Jack Receptacle - Round Contact JOHNSON COMPONENTS 142-0711-821 1019328    16F3627

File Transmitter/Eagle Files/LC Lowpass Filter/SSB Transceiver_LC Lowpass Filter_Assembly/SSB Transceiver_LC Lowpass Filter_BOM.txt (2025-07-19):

Partlist exported from E:/Simon Dorrer/DIY Projekte/Amateurfunkprojekte/SSB Transceiver/Transmitter/Eagle Files/LC Lowpass Filter/SSB Transceiver_LC Lowpass Filter.sch at 20/01/2020 16:40

Qty Value   Device               Package                  Parts  Description                                           MF                 MPN          OC_FARNELL OC_NEWARK POPULARITY SPICEPREFIX
2   180pF   C-EUC0805            C0805                    C1, C3 CAPACITOR, European symbol                                                                                 88         C          
1   330pF   C-EUC0805            C0805                    C2     CAPACITOR, European symbol                                                                                 88         C          
2   580nH   T50-6                T50-6SMD                 L1, L2                                                                                                                                  
1   SMA_IN  SMA-142-0711-821/826 J502-ND-142-0711-821/826 X1     SMA 50 Ohm End Launch Jack Receptacle - Round Contact JOHNSON COMPONENTS 142-0711-821 1019328    16F3627                         
1   SMA_OUT SMA-142-0711-821/826 J502-ND-142-0711-821/826 X2     SMA 50 Ohm End Launch Jack Receptacle - Round Contact JOHNSON COMPONENTS 142-0711-821 1019328    16F3627

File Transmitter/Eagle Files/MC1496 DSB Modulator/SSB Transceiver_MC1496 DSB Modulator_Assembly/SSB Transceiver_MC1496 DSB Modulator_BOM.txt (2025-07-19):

Partlist exported from E:/Simon Dorrer/DIY Projekte/Amateurfunkprojekte/SSB Transceiver/Transmitter/Eagle Files/MC1496 DSB Modulator/SSB Transceiver_MC1496 DSB Modulator.sch at 12/01/2020 14:15

Qty Value      Device               Package                  Parts            Description                                           AVAILABILITY DESCRIPTION                                     MF                 MP         MPN          OC_FARNELL OC_NEWARK PACKAGE                  POPULARITY PRICE SPICEPREFIX
1   1.2k       R-EU_R0805           R0805                    R10              RESISTOR, European symbol                                                                                                                                                                                   86               R          
3   100R       R-EU_R0805           R0805                    R3, R5, R14      RESISTOR, European symbol                                                                                                                                                                                   86               R          
4   100nF      C-EUC0805            C0805                    C5, C8, C11, C13 CAPACITOR, European symbol                                                                                                                                                                                  88               C          
3   10k        R-EU_R0805           R0805                    R2, R6, R11      RESISTOR, European symbol                                                                                                                                                                                   86               R          
1   10k        TRIM_EU-3223G        3223G                    R1               POTENTIOMETER                                                                                                                                                                                                                           
1   12V        AK300/2              AK300/2                  X4               CONNECTOR                                                                                                                                                     unknown    unknown                                                        
2   1k         R-EU_R0805           R0805                    R8, R12          RESISTOR, European symbol                                                                                                                                                                                   86               R          
2   1nF        C-EUC0805            C0805                    C1, C12          CAPACITOR, European symbol                                                                                                                                                                                  88               C          
3   1uF        C-EUC0805            C0805                    C2, C7, C9       CAPACITOR, European symbol                                                                                                                                                                                  88               C          
2   2.2u       C-EUC0805            C0805                    C4, C6           CAPACITOR, European symbol                                                                                                                                                                                  88               C          
1   220nF      C-EUC0805            C0805                    C3               CAPACITOR, European symbol                                                                                                                                                                                  88               C          
1   3k       R-EU_R0805           R0805                    R13              RESISTOR, European symbol                                                                                                                                                                                   86               R          
1   50k        TRIM_EU-3223G        3223G                    R4               POTENTIOMETER                                                                                                                                                                                                                           
1   50pF       VARIABLECAP          VARIABLECAP-SMD          C10                                                                                                                                                                                                                                                      
1   51R        R-EU_R0805           R0805                    R9               RESISTOR, European symbol                                                                                                                                                                                   86               R          
1   820        R-EU_R0805           R0805                    R7               RESISTOR, European symbol                                                                                                                                                                                   86               R          
1   AF_IN      AK300/2              AK300/2                  X2               CONNECTOR                                                                                                                                                     unknown    unknown                                                        
1   FT37-43    FT37-43CENTERTAP     FT37-43CENTERTAPSMD      T1                                                                                                                                                                                                                                                       
1   MC1496DR2G MC1496DR2G           SOIC127P600X175-14N      U1                                                                     Unavailable   RF IC Modulator/Demodulator FM 300MHz 14-SOIC  ON Semiconductor   MC1496DR2G                                   SOIC-14 ON Semiconductor            None             
1   OSC. IN    SMA-142-0711-821/826 J502-ND-142-0711-821/826 X1               SMA 50 Ohm End Launch Jack Receptacle - Round Contact                                                              JOHNSON COMPONENTS            142-0711-821 1019328    16F3627                                                        
1   SMA_OUT    SMA-142-0711-821/826 J502-ND-142-0711-821/826 X3               SMA 50 Ohm End Launch Jack Receptacle - Round Contact                                                              JOHNSON COMPONENTS            142-0711-821 1019328    16F3627

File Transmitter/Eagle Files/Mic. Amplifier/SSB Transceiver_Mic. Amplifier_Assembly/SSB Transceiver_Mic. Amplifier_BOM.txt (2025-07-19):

Partlist exported from E:/Simon Dorrer/DIY Projekte/Amateurfunkprojekte/SSB Transceiver/Transmitter/Eagle Files/Mic. Amplifier/SSB Transceiver_Mic. Amplifier.sch at 06/01/2020 22:23

Qty Value   Device               Package    Parts          Description                MF MPN OC_FARNELL OC_NEWARK POPULARITY PROD_ID    SF_ID     SPICEPREFIX
3   0R      R-EU_R0805           R0805      R1, R2, R3     RESISTOR, European symbol                              86                              R          
1   1.2nF   C-EUC0805            C0805      C9             CAPACITOR, European symbol                             88                              C          
2   100k    R-EU_R0805           R0805      R5, R6         RESISTOR, European symbol                              86                              R          
4   100nF   C-EUC0805            C0805      C2, C4, C5, C7 CAPACITOR, European symbol                             88                              C          
2   10k     R-EU_R0805           R0805      R17, R18       RESISTOR, European symbol                              86                              R          
2   10k     TRIM_EU-3223G        3223G      R8, R20        POTENTIOMETER                                                                                     
1   10nF    C-EUC0805            C0805      C11            CAPACITOR, European symbol                             88                              C          
2   10uF    C-EUC0805            C0805      C3, C12        CAPACITOR, European symbol                             88                              C          
1   12V     AK550/2              AK550/2    X2             CONNECTOR                         unknown    unknown
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

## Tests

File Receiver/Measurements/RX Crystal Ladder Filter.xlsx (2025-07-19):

RX Crystal Ladder Filter:
dB | f in MHz
-26.021 | 8.9980
-20.000 | 8.9985
-9.753 | 8.9990
-5.036 | 8.9993 | fcl
-4.883 | 8.9995
-2.095 | 9.0005 | max.
-3.350 | 9.0010
-5.710 | 9.0015
-1.671 | 9.0020
-5.075 | 9.0022 | fcu
-8.127 | 9.0025
-12.736 | 9.0030
-29.542 | 9.0035
 | 9.0008 | fcenter
B | 2.9 | kHz

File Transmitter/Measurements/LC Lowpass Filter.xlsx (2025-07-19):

LC Lowpass Filter:
dB | f in MHz
-0.35 | 1.00
-0.92 | 10.00
-1.11 | 12.00
-1.41 | 14.00
-1.51 | 14.50
-1.72 | 15.00
-2.27 | 16.00
-2.97 | 17.00 | fc
-3.74 | 18.00
-4.73 | 19.00
-6.02 | 20.00
-11.37 | 22.00
-15.39 | 25.00

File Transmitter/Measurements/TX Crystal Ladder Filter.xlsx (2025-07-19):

TX Crystal Ladder Filter:
dB | f in MHz
-27.604 | 8.9970
-21.584 | 8.9980
-16.478 | 8.9985
-8.715 | 8.9990
-4.933 | 8.9992 | fcl
-2.537 | 8.9995
-3.522 | 9.0000
-2.499 | 9.0005
-1.938 | 9.0010 | max.
-2.499 | 9.0015
-2.694 | 9.0020
-4.933 | 9.0025 | fcu
-7.604 | 9.0030
-21.584 | 9.0035
-27.604 | 9.0040
B | 3.3 | kHz

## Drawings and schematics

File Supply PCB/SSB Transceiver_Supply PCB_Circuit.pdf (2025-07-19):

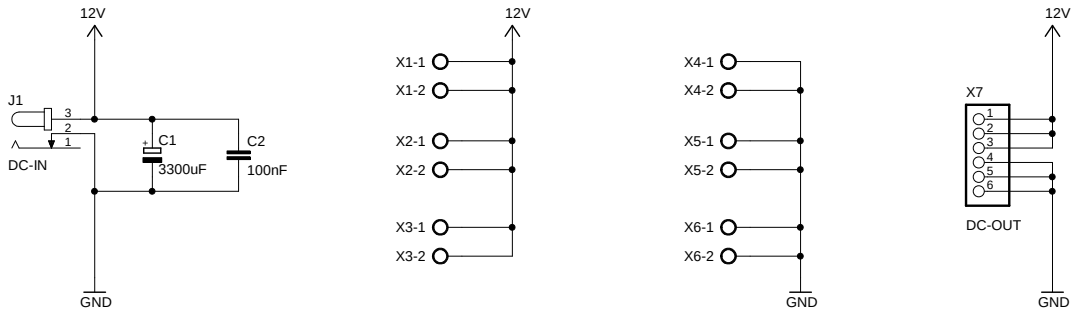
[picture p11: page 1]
6 X7 Date:; Sheet:; REV: TITLE: Document Number: 14/03/2020 20:45; 1/1 SSB Transceiver_Supply PCB

14/03/2020 20:47 E:\Simon Dorrer\DIY Projekte\Amateurfunkprojekte\SSB Transceiver\Supply PCB\SSB Transceiver_Supply PCB.sch (Sheet: 1/1) DC-IN 3300uF 100nF 12V GND GND 12V DC-OUT 12V GND X1-1 X1-2 X2-1 X2-2 X3-1 X3-2 X4-1 X4-2 X5-1 X5-2 X6-1 X6-2

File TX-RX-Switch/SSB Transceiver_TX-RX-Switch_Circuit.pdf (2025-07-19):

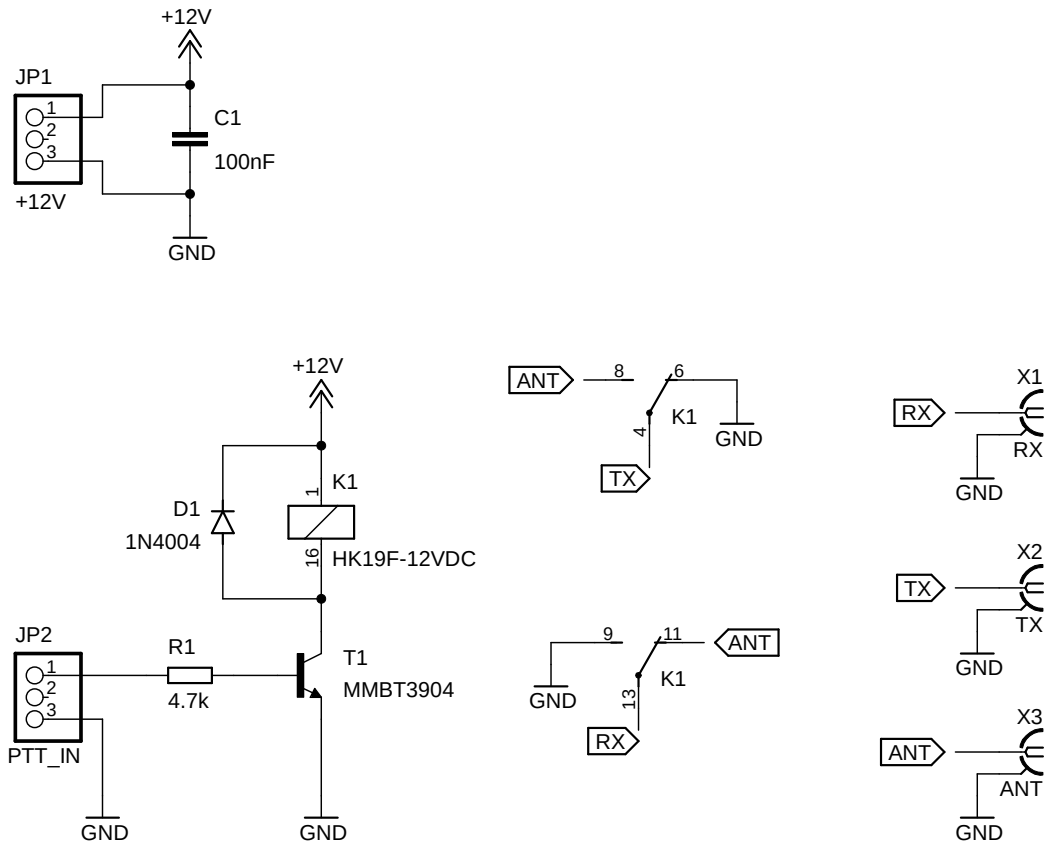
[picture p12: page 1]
MMBT3904; GND; PTT_IN; ANT; HK19F-12VDC; TITLE:

SSB Transceiver_TX-RX-Switch

Document Number: | REV:

Date: 13/04/2020 13:03 | Sheet: 1/1

13/04/2020 13:03 E:\Simon Dorrer\DIY Projekte\Amateurfunkprojekte\SSB Transceiver\TX-RX-Switch\SSB Transceiver_TX-RX-Switch.sch (Sheet: 1/1)

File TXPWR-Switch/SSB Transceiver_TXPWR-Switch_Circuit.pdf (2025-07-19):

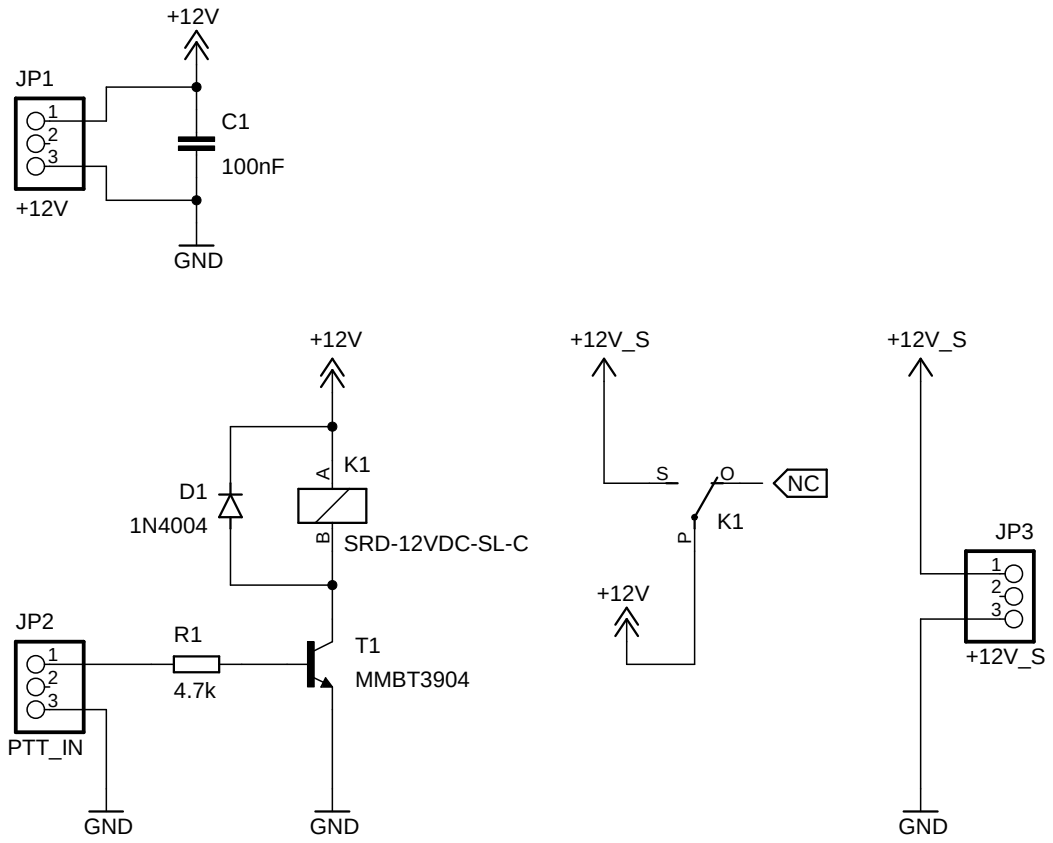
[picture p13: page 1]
MMBT3904; GND; PTT_IN; SRD-12VDC-SL-C; TITLE:; SSB Transceiver_TXPWR-Switch

Document Number: | REV:

Date: 13/04/2020 13:48 | Sheet: 1/1

13/04/2020 13:48 E:\Simon Dorrer\DIY Projekte\Amateurfunkprojekte\SSB Transceiver\TXPWR-Switch\SSB Transceiver_TXPWR-Switch.sch (Sheet: 1/1)

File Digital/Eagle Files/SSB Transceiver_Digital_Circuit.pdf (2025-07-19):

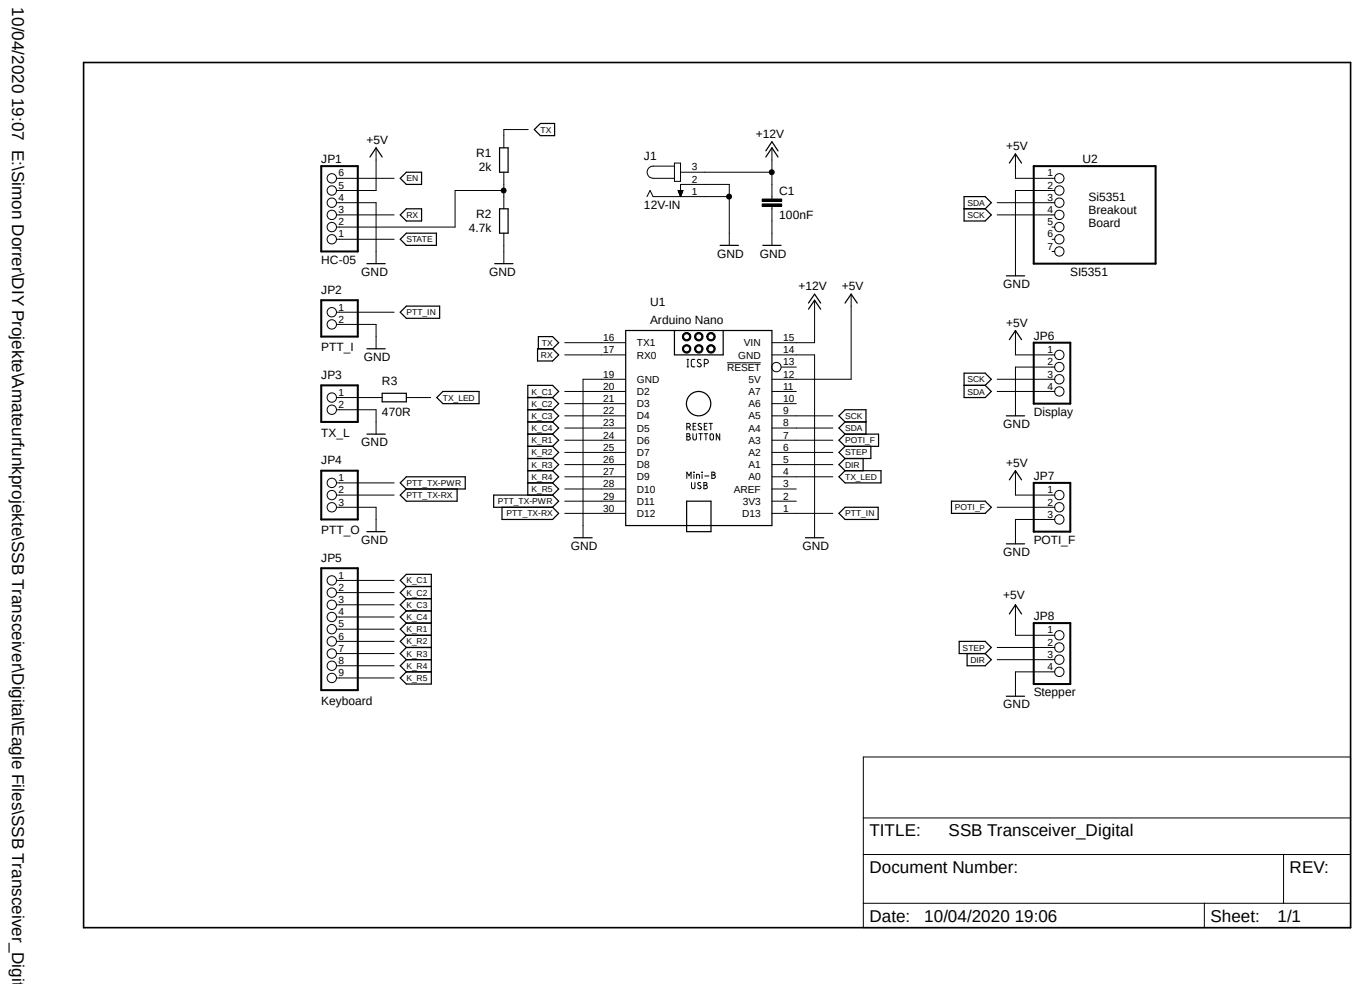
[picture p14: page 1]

10/04/2020 19:07 E:\Simon Dorrer\DIY Projekte\Amateurfunkprojekte\SSB Transceiver\Digital\Eagle Files\SSB Transceiver_Digital.sch (Sheet: 1/1) Arduino Nano +12V +5V GND 12V-IN GND GND100nF +12V GND PTT_I TX_L PTT_O POTI_F Display KeyboardGND GND GND +5V +5V GND GND +5V GND +5V GND SI5351 2k 4.7k HC-05 GND GND +5V Stepper 470R TX1 16 RX0 17 GND 19 D2 20 D3 21 D4 22 D5 23 D6 24 D7 25 D8 26 D9 27 D10 28 D11 29 D12 30 D13

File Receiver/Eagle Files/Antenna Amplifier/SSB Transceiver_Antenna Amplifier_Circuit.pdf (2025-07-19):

2JP1 | C1 | Date: | Sheet: | REV: TITLE: Document Number: 29/01/2020 12:29 | 1/1 SSB Transceiver_Antenna Amplifier

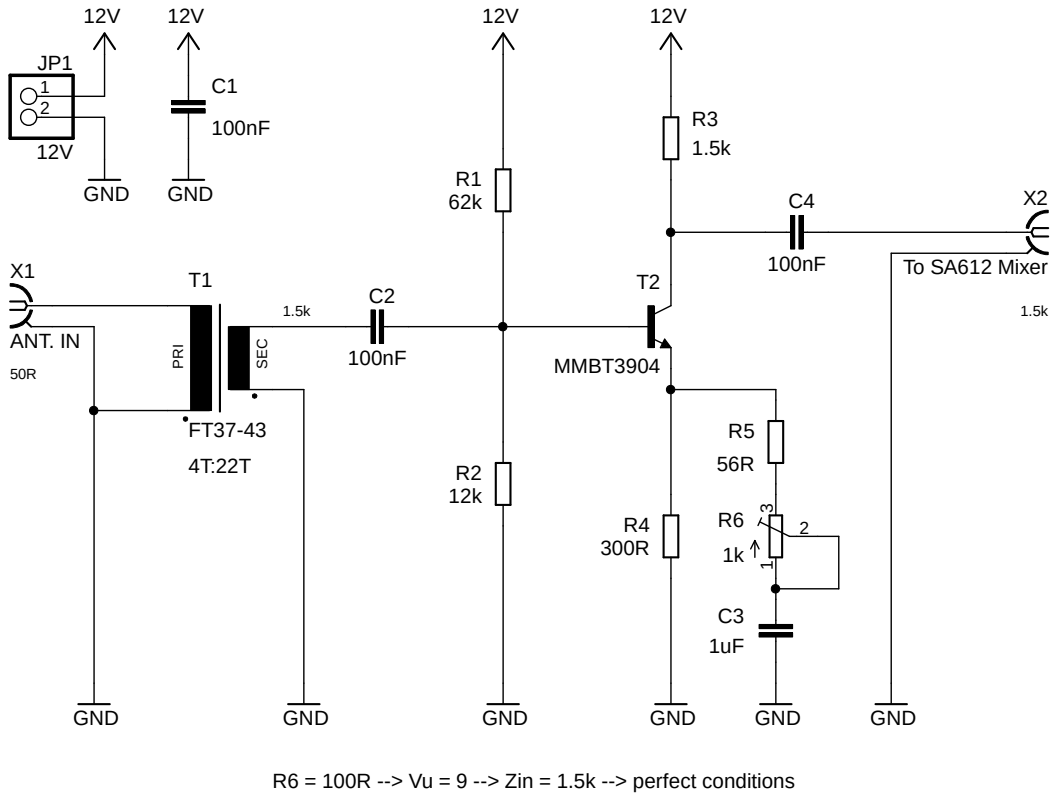
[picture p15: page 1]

29/01/2020 12:29 E:\Simon Dorrer\DIY Projekte\Amateurfunkprojekte\SSB Transceiver\Receiver\Eagle Files\Antenna Amplifier\SSB Transceiver_Antenna Amplifier.sch (Sheet: 1/1) 50R 1.5k 4T:22T 1.5k R6 = 100R --> Vu = 9 --> Zin = 1.5k --> perfect conditions FT37-43 ANT. IN To SA612 Mixer 100nF 1uF 62k 12k 300R12V GND MMBT3904 1k GND GND GND 12V 1.5k56R 100nF GND 12V 12V GND100nF GND 12V GND T1 X1 X2 C2 C3 R1 R2 R4T2

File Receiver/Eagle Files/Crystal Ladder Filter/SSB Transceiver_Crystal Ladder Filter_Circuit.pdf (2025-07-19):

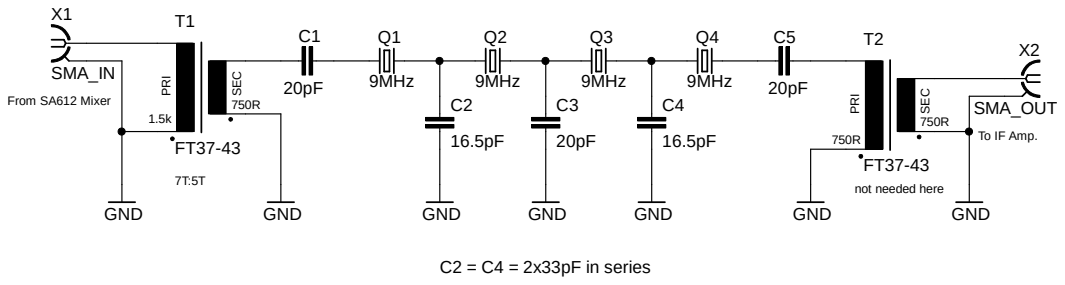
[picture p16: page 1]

13/01/2020 09:38 E:\Simon Dorrer\DIY Projekte\Amateurfunkprojekte\SSB Transceiver\Receiver\Eagle Files\Crystal Ladder Filter\SSB Transceiver_Crystal Ladder Filter.sch (Sheet: 1/1) 7T:5T 1.5k 750R 750R 750R C2 = C4 = 2x33pF in series From SA612 Mixer To IF Amp. not needed here SMA_OUT 9MHz 9MHz 9MHz 9MHz 20pF 16.5pF 20pF 16.5pF 20pF GND GND GND SMA_INGND GND FT37-43 FT37-43 GND GND X2 C1 Q1 Q2 Q3 Q4 C2 C3 C4 C5 X1 T1 T2 Date: Sheet: REV: TITLE: Document Number: 13/01/2020 09:37 1/1 SSB Transceiver_Crystal Ladder Filter

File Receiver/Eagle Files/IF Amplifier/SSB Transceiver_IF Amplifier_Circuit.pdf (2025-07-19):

2JP1 | C1 | Date: | Sheet: | REV: TITLE: Document Number: 29/01/2020 12:32 | 1/1 SSB Transceiver_IF Amplifier

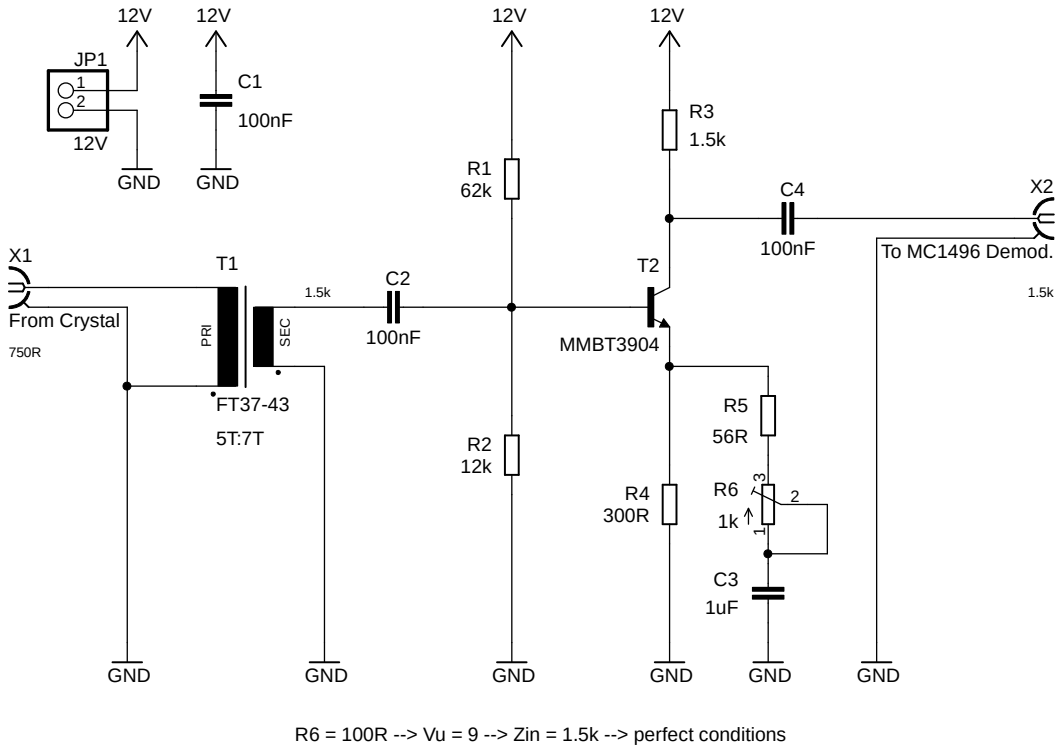
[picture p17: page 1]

29/01/2020 12:32 E:\Simon Dorrer\DIY Projekte\Amateurfunkprojekte\SSB Transceiver\Receiver\Eagle Files\IF Amplifier\SSB Transceiver_IF Amplifier.sch (Sheet: 1/1) 750R 1.5k 5T:7T 1.5k R6 = 100R --> Vu = 9 --> Zin = 1.5k --> perfect conditions FT37-43 From Crystal To MC1496 Demod. 100nF 1uF 62k 12k 300R12V GND MMBT3904 1k GND GND GND 12V 1.5k56R 100nF GND 12V 12V GND100nF GND 12V GND T1 X1 X2 C2 C3 R1 R2 R4T2

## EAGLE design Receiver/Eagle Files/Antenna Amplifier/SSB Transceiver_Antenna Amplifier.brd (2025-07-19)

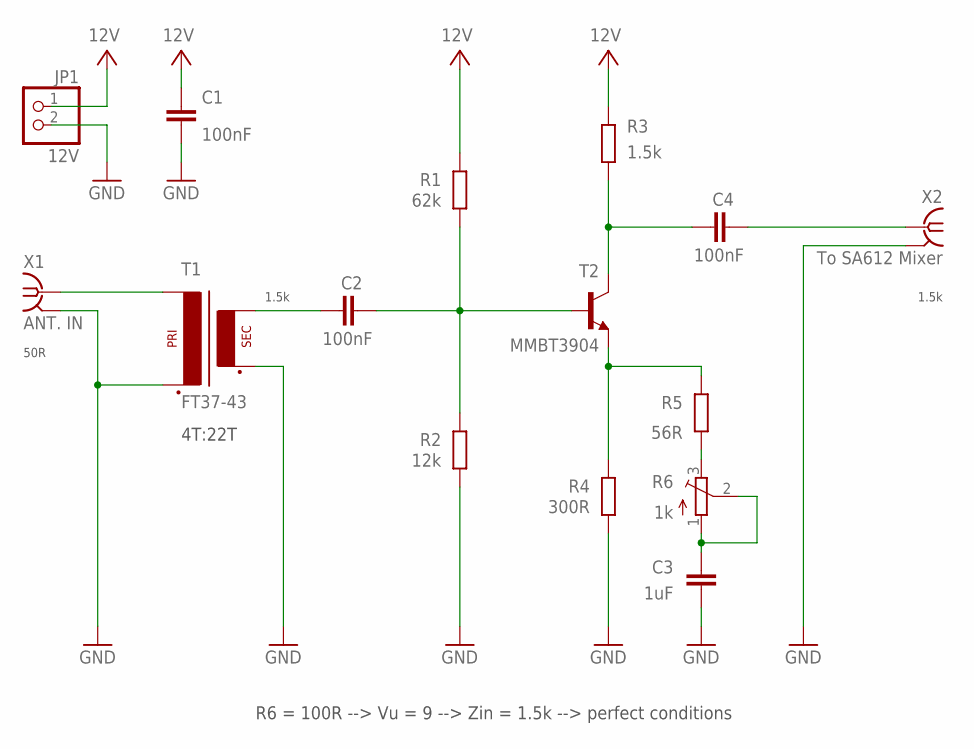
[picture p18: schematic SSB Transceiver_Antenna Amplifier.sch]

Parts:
C1, C2, C4: 100nF; C0805
C3: 1uF; C0805
JP1: 12V; 1X02
R1: 62k; R0805
R2: 12k; R0805
R3: 1.5k; R0805
R4: 300R; R0805
R5: 56R; R0805
R6: 1k; 3223G
T1: FT37-43; FT37-43SMD
T2: MMBT3904; SOT23-BEC
X1: ANT. IN; J502-ND-142-0711-821/826
X2: To SA612 Mixer; J502-ND-142-0711-821/826

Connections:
GND: C1.1, C3.1, JP1.2, R2.2, R4.2, T1.P$2 (P2), T1.S$2 (S2), X1.G@1 (2), X1.G@2 (2), X1.G@3 (2), X1.G@4 (2), X2.G@1 (2), X2.G@2 (2), X2.G@3 (2), X2.G@4 (2)
unnamed: R4.1, R5.1, T2.E
unnamed: C3.2, R6.1 (A), R6.2 (S)
unnamed: C4.1, R3.2, T2.C
unnamed: T1.P$1 (P1), X1.1
unnamed: C2.2, R1.2, R2.1, T2.B
unnamed: C4.2, X2.1
unnamed: C2.1, T1.S$1 (S1)
unnamed: R5.2, R6.3 (E)
VCC: C1.2, JP1.1, R1.1, R3.1

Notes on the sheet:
50R
1.5k
4T:22T
R6 = 100R --> Vu = 9 --> Zin = 1.5k --> perfect conditions

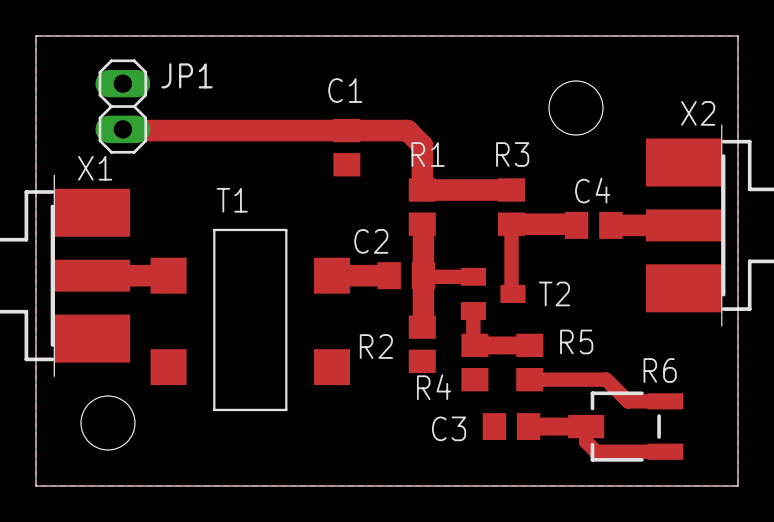
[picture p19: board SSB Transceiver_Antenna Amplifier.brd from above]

Board: 2 copper layers, 39.0 x 25.0 mm, 15 parts (0 on the bottom side), 10 nets.

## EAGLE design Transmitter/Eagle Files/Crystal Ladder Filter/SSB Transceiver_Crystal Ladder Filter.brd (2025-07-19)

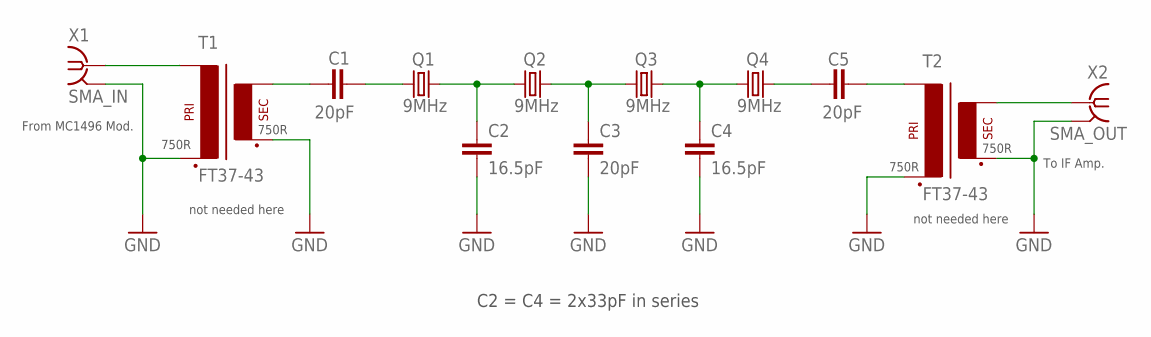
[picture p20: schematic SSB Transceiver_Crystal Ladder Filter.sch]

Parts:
C1, C3, C5: 20pF; C0805
C2, C4: 16.5pF; C0805
Q1, Q2, Q3, Q4: 9MHz; HC49/S
T1, T2: FT37-43; FT37-43SMD
X1: SMA_IN; J502-ND-142-0711-821/826
X2: SMA_OUT; J502-ND-142-0711-821/826

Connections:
GND: C2.2, C3.2, C4.2, T1.P$2 (P2), T1.S$2 (S2), T2.P$2 (P2), T2.S$2 (S2), X1.G@1 (2), X1.G@2 (2), X1.G@3 (2), X1.G@4 (2), X2.G@1 (2), X2.G@2 (2), X2.G@3 (2), X2.G@4 (2)
unnamed: C5.2, T2.P$1 (P1)
unnamed: T2.S$1 (S1), X2.1
unnamed: C1.1, T1.S$1 (S1)
unnamed: T1.P$1 (P1), X1.1
unnamed: C1.2, Q1.1
unnamed: C2.1, Q1.2, Q2.1
unnamed: C3.1, Q2.2, Q3.1
unnamed: C4.1, Q3.2, Q4.1
unnamed: C5.1, Q4.2

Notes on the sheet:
not needed here
750R
C2 = C4 = 2x33pF in series
From MC1496 Mod.
To IF Amp.

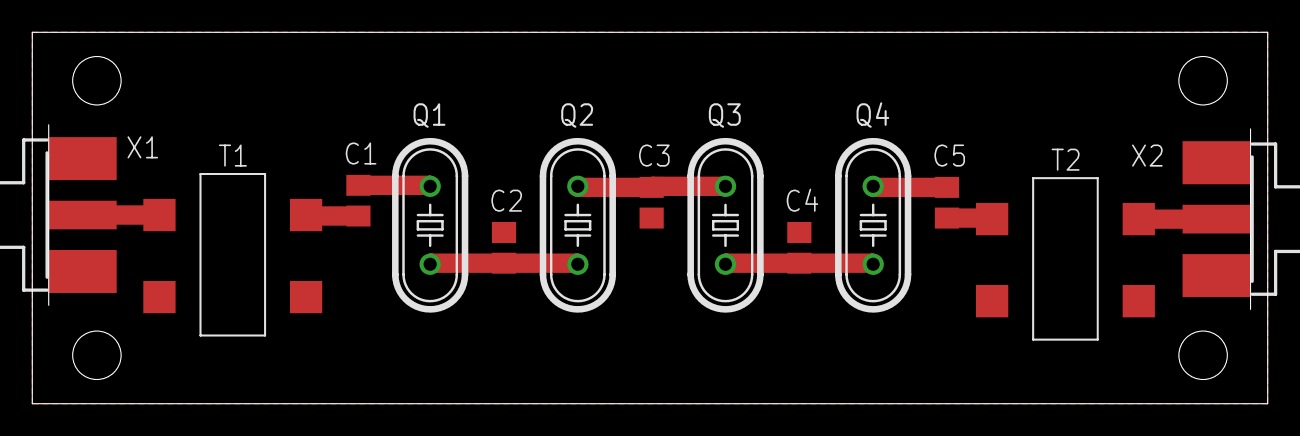
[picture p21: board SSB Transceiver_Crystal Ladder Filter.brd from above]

Board: 2 copper layers, 76.5 x 23.0 mm, 13 parts (0 on the bottom side), 10 nets.

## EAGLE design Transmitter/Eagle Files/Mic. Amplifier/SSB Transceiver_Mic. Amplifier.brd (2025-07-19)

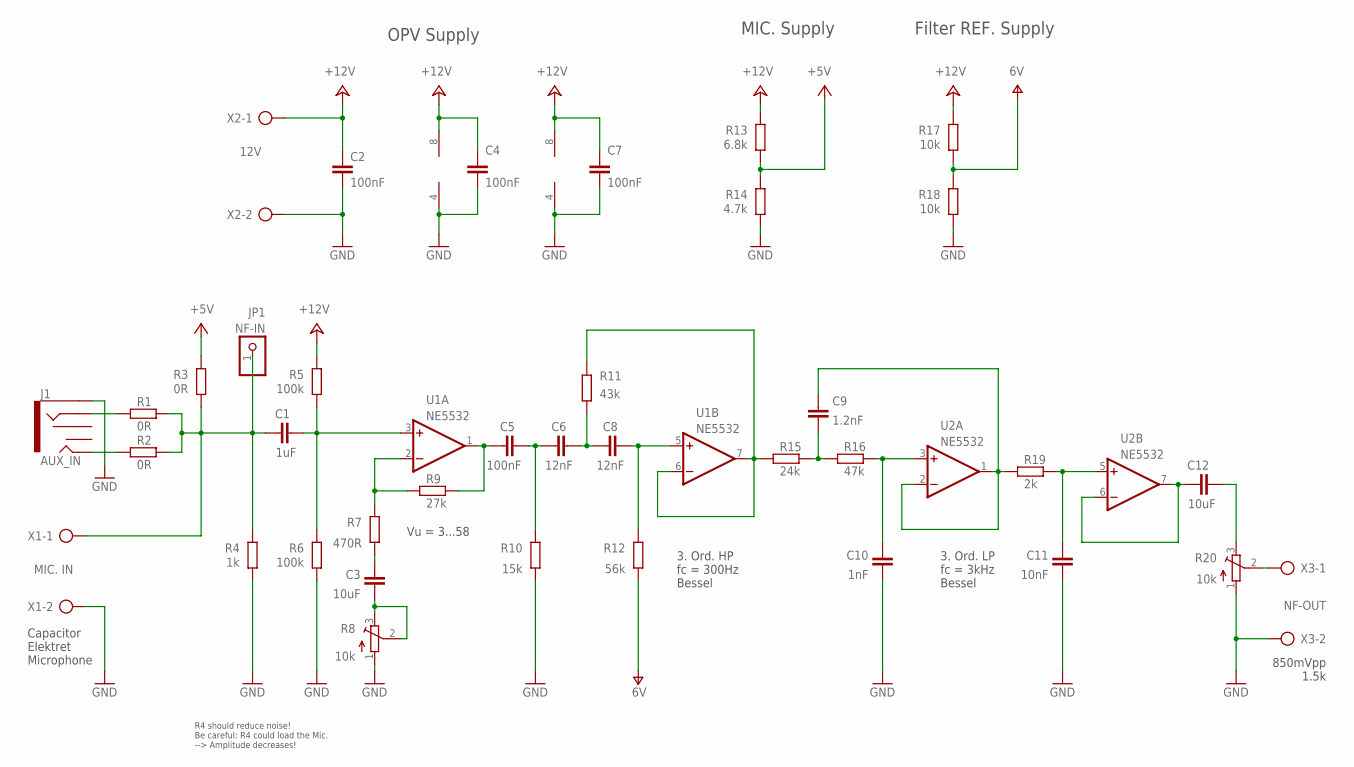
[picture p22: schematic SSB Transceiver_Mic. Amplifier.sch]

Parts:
C1: 1uF; C0805
C2, C4, C5, C7: 100nF; C0805
C3, C12: 10uF; C0805
C6, C8: 12nF; C0805
C9: 1.2nF; C0805
C10: 1nF; C0805
C11: 10nF; C0805
J1: AUX_IN; AUDIO-JACK
JP1: NF-IN; 1X01
R1, R2, R3: 0R; R0805
R4: 1k; R0805
R5, R6: 100k; R0805
R7: 470R; R0805
R8, R20: 10k; 3223G
R9: 27k; R0805
R10: 15k; R0805
R11: 43k; R0805
R12: 56k; R0805
R13: 6.8k; R0805
R14: 4.7k; R0805
R15: 24k; R0805
R16: 47k; R0805
R17, R18: 10k; R0805
R19: 2k; R0805
U1, U2: NE5532; SO08
X1: MIC. IN; AK550/2
X2: 12V; AK550/2
X3: NF-OUT; AK550/2

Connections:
+5V: R3.1, R13.2, R14.1
+24V: C2.2, C4.2, C7.2, R5.1, R13.1, R17.1, U1.8 (V+), U2.8 (V+), X2.1
GND: C2.1, C4.1, C7.1, C10.1, C11.1, J1.SLEEVE, R4.2, R6.2, R8.1 (A), R10.2, R14.2, R18.2, R20.1 (A), U1.4 (V-), U2.4 (V-), X1.2, X2.2, X3.2
unnamed: J1.RING, R1.2
unnamed: J1.TIP, R2.2
unnamed: R7.1, R9.1, U1.2 (-IN)
unnamed: C1.1, JP1.1, R1.1, R2.1, R3.2, R4.1, X1.1
unnamed: C1.2, R5.2, R6.1, U1.3 (+IN)
unnamed: C3.2, R7.2
unnamed: C3.1, R8.2 (S), R8.3 (E)
unnamed: C5.1, R9.2, U1.1 (OUT)
unnamed: C5.2, C6.1, R10.1
unnamed: C12.1, U2.6 (-IN), U2.7 (OUT)
unnamed: R20.2 (S), X3.1
unnamed: C12.2, R20.3 (E)
unnamed: R11.1, R15.2, U1.6 (-IN), U1.7 (OUT)
unnamed: C6.2, C8.1, R11.2
unnamed: C8.2, R12.1, U1.5 (+IN)
unnamed: C9.1, R15.1, R16.2
unnamed: C10.2, R16.1, U2.3 (+IN)
unnamed: C9.2, R19.2, U2.1 (OUT), U2.2 (-IN)
unnamed: C11.2, R19.1, U2.5 (+IN)
V+: R12.2, R17.2, R18.1

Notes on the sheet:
Capacitor Elektret Microphone
OPV Supply
MIC. Supply
Filter REF. Supply
Vu = 3...58
3. Ord. HP fc = 300Hz Bessel
3. Ord. LP fc = 3kHz Bessel
850mVpp 1.5k
R4 should reduce noise! Be careful: R4 could load the Mic. --> Amplitude decreases!

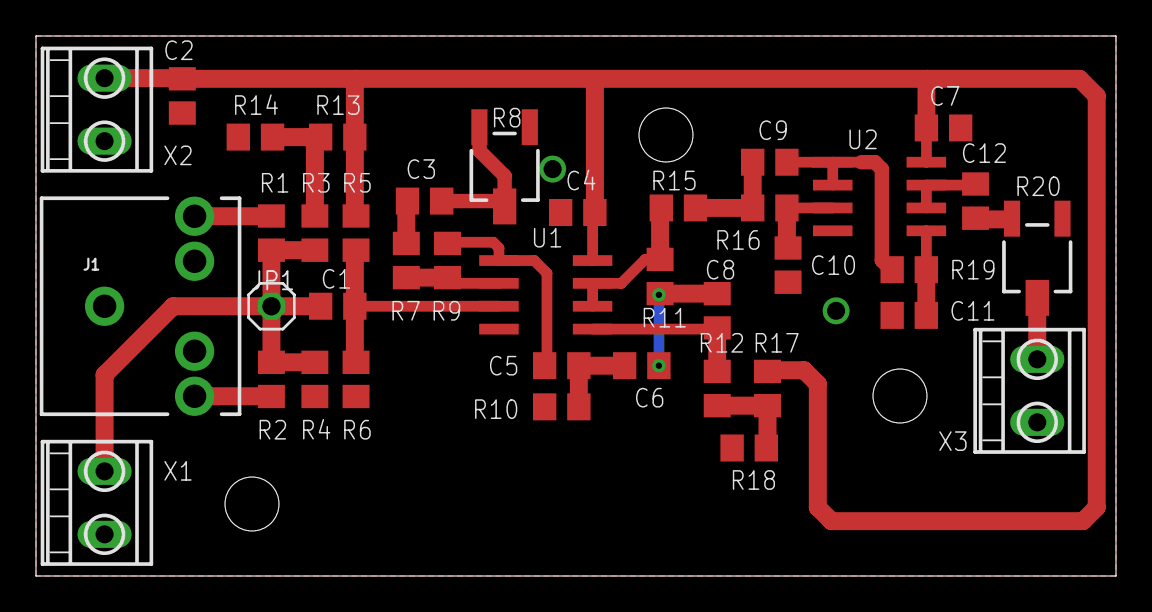
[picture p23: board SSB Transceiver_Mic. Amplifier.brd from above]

Board: 2 copper layers, 60.0 x 30.0 mm, 39 parts (0 on the bottom side), 23 nets.

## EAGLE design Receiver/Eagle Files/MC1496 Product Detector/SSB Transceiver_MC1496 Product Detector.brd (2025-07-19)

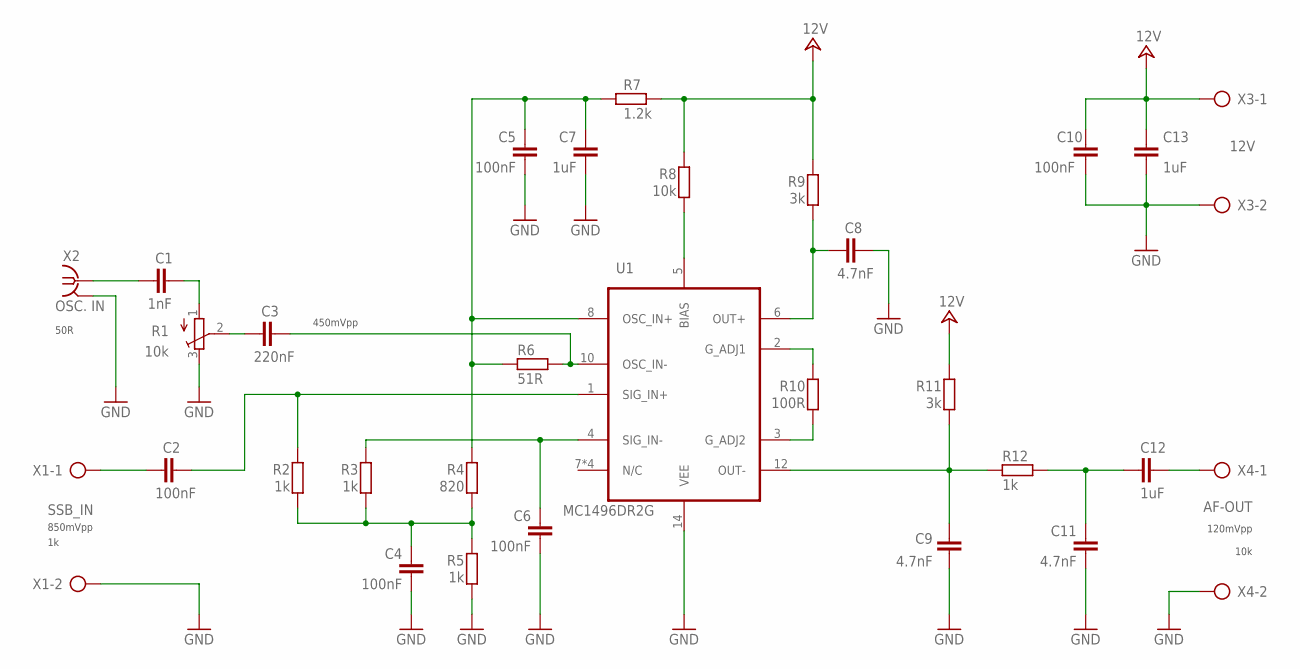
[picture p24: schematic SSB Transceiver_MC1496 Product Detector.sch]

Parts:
C1: 1nF; C0805
C2, C4, C5, C6, C10: 100nF; C0805
C3: 220nF; C0805
C7, C12, C13: 1uF; C0805
C8, C9, C11: 4.7nF; C0805
R1: 10k; 3223G
R2, R3, R5, R12: 1k; R0805
R4: 820; R0805
R6: 51R; R0805
R7: 1.2k; R0805
R8: 10k; R0805
R9, R11: 3k; R0805
R10: 100R; R0805
U1: MC1496DR2G; SOIC127P600X175-14N
X1: SSB_IN; AK300/2
X2: OSC. IN; J502-ND-142-0711-821/826
X3: 12V; AK300/2
X4: AF-OUT; AK300/2

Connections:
+24V: C10.2, C13.2, R7.2, R8.1, R9.1, R11.1, X3.1
GND: C4.1, C5.1, C6.1, C7.1, C8.1, C9.1, C10.1, C11.1, C13.1, R1.3 (E), R5.1, U1.14 (VEE), X1.2, X2.G@1 (2), X2.G@2 (2), X2.G@3 (2), X2.G@4 (2), X3.2, X4.2
unnamed: C1.1, X2.1
unnamed: C12.2, X4.1
unnamed: C1.2, R1.1 (A)
unnamed: C3.1, R1.2 (S)
unnamed: C8.2, R9.2, U1.6 (OUT+)
unnamed: C9.2, R11.2, R12.1, U1.12 (OUT-)
unnamed: C11.2, C12.1, R12.2
unnamed: R10.2, U1.3 (G_ADJ2)
unnamed: R10.1, U1.2 (G_ADJ1)
unnamed: C3.2, R6.2, U1.10 (OSC_IN-)
unnamed: R8.2, U1.5 (BIAS)
unnamed: C6.2, R3.1, U1.4 (SIG_IN-)
unnamed: C2.2, R2.2, U1.1 (SIG_IN+)
unnamed: C4.2, R2.1, R3.2, R4.1, R5.2
unnamed: C2.1, X1.1
unnamed: C5.2, C7.2, R4.2, R6.1, R7.1, U1.8 (OSC_IN+)

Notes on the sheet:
10k
120mVpp
50R
450mVpp
850mVpp

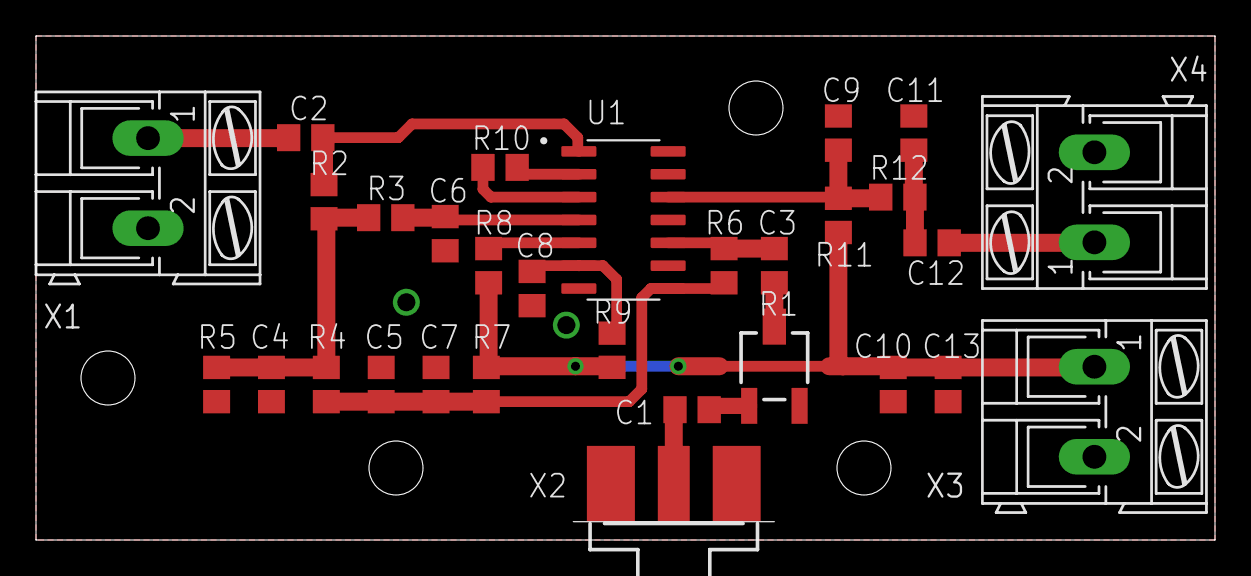
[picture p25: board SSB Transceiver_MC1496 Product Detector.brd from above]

Board: 2 copper layers, 65.5 x 28.0 mm, 30 parts (0 on the bottom side), 18 nets.

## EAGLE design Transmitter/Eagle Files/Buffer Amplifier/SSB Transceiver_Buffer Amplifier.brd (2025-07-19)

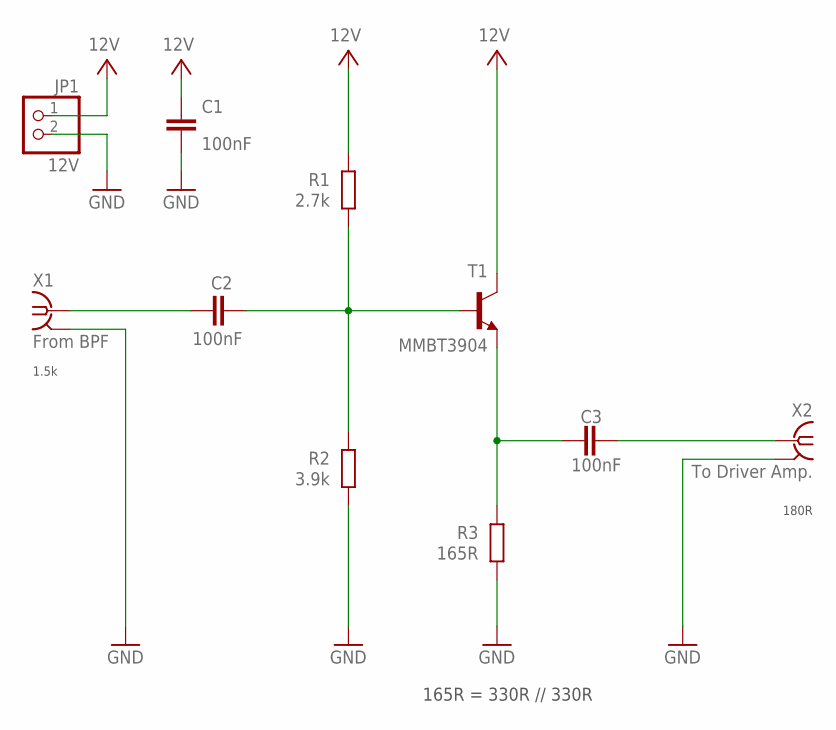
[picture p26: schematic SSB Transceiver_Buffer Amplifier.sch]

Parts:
C1, C2, C3: 100nF; C0805
JP1: 12V; 1X02
R1: 2.7k; R0805
R2: 3.9k; R0805
R3: 165R; R0805
T1: MMBT3904; SOT23-BEC
X1: From BPF; J502-ND-142-0711-821/826
X2: To Driver Amp.; J502-ND-142-0711-821/826

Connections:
GND: C1.1, JP1.2, R2.2, R3.2, X1.G@1 (GND), X1.G@2 (GND), X1.G@3 (GND), X1.G@4 (GND), X2.G@1 (GND), X2.G@2 (GND), X2.G@3 (GND), X2.G@4 (GND)
unnamed: C3.2, R3.1, T1.E
unnamed: C3.1, X2.1 (RF)
unnamed: C2.2, R1.2, R2.1, T1.B
unnamed: C2.1, X1.1 (RF)
VCC: C1.2, JP1.1, R1.1, T1.C

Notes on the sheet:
1.5k
180R
165R = 330R // 330R

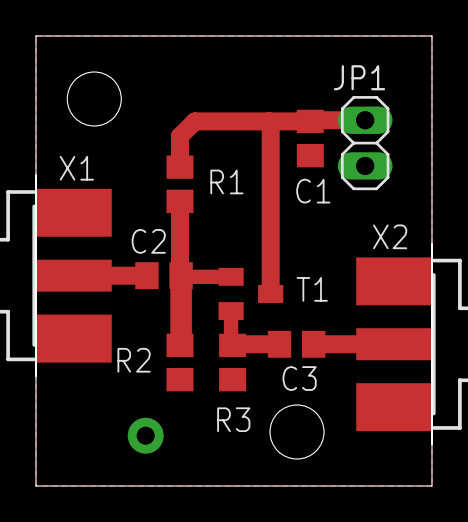
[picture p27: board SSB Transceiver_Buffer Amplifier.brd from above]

Board: 2 copper layers, 22.0 x 25.0 mm, 10 parts (0 on the bottom side), 6 nets.

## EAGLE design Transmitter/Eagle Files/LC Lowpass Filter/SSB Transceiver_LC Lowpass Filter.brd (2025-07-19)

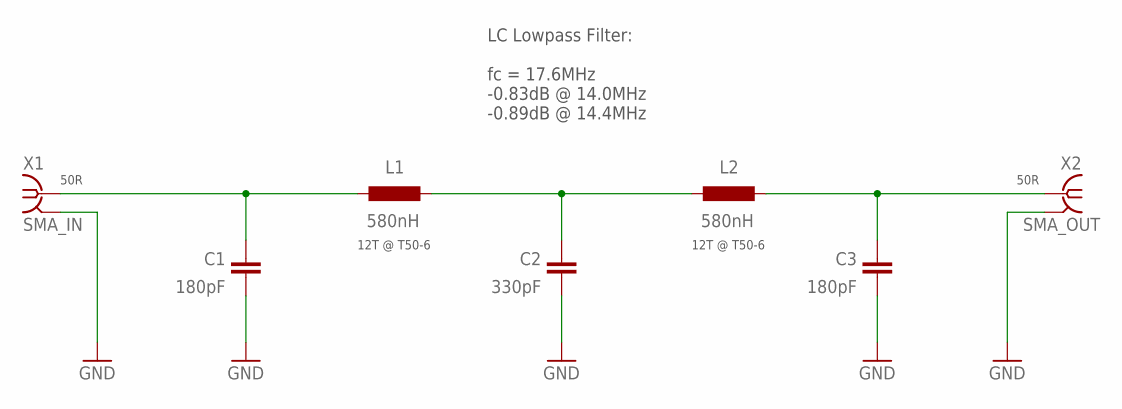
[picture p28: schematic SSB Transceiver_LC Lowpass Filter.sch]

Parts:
C1, C3: 180pF; C0805
C2: 330pF; C0805
L1, L2: 580nH; T50-6SMD
X1: SMA_IN; J502-ND-142-0711-821/826
X2: SMA_OUT; J502-ND-142-0711-821/826

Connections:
GND: C1.1, C2.1, C3.1, X1.G@1 (2), X1.G@2 (2), X1.G@3 (2), X1.G@4 (2), X2.G@1 (2), X2.G@2 (2), X2.G@3 (2), X2.G@4 (2)
unnamed: C2.2, L1.P$2 (2), L2.P$1 (1)
unnamed: C3.2, L2.P$2 (2), X2.1
unnamed: C1.2, L1.P$1 (1), X1.1

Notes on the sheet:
50R
LC Lowpass Filter: fc = 17.6MHz -0.83dB @ 14.0MHz -0.89dB @ 14.4MHz
12T @ T50-6

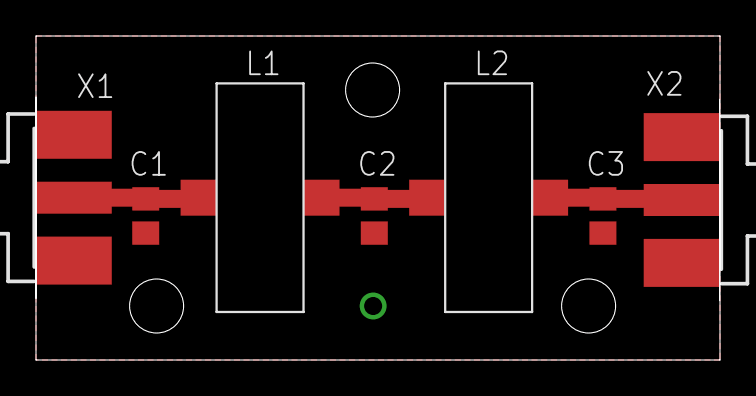
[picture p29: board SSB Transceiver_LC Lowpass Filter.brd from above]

Board: 2 copper layers, 38.0 x 18.0 mm, 7 parts (0 on the bottom side), 4 nets.

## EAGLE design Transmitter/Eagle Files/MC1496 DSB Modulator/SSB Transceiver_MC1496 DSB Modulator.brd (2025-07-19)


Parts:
C1, C12: 1nF; C0805
C2, C7, C9: 1uF; C0805
C3: 220nF; C0805
C4, C6: 2.2u; C0805
C5, C8, C11, C13: 100nF; C0805
C10: 50pF; VARIABLECAP-SMD
R1: 10k; 3223G
R2, R6, R11: 10k; R0805
R3, R5, R14: 100R; R0805
R4: 50k; 3223G
R7: 820; R0805
R8, R12: 1k; R0805
R9: 51R; R0805
R10: 1.2k; R0805
R13: 3k; R0805
T1: FT37-43; FT37-43CENTERTAPSMD
U1: MC1496DR2G; SOIC127P600X175-14N
X1: OSC. IN; J502-ND-142-0711-821/826
X2: AF_IN; AK300/2
X3: SMA_OUT; J502-ND-142-0711-821/826
X4: 12V; AK300/2

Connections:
+24V: C13.2, R14.2, X4.1
GND: C4.1, C5.1, C6.1, C7.1, C8.1, C9.1, C11.1, C13.1, R1.3 (E), R4.2 (S), R8.1, T1.S$2 (S2), U1.14 (VEE), X1.G@1 (2), X1.G@2 (2), X1.G@3 (2), X1.G@4 (2), X2.2, X3.G@1 (2), X3.G@2 (2), X3.G@3 (2), X3.G@4 (2), X4.2
unnamed: C1.1, X1.1
unnamed: C12.2, X3.1
unnamed: C1.2, R1.1 (A)
unnamed: C3.1, R1.2 (S)
unnamed: C8.2, C9.2, C11.2, R10.2, R11.1, R14.1, T1.P$2 (P1_2), T1.P$3 (P2_1)
unnamed: C12.1, T1.S$1 (S1)
unnamed: C10.P$1 (E), R13.1, T1.P$1 (P1_1), U1.6 (OUT+)
unnamed: C10.P$2 (A), R13.2, T1.P$4 (P2_2), U1.12 (OUT-)
unnamed: R12.2, U1.3 (G_ADJ2)
unnamed: R12.1, U1.2 (G_ADJ1)
unnamed: C3.2, R9.2, U1.10 (OSC_IN-)
unnamed: R11.2, U1.5 (BIAS)
unnamed: R2.1, R4.1 (A)
unnamed: R4.3 (E), R6.2
unnamed: C6.2, R5.2, R6.1, U1.4 (SIG_IN-)
unnamed: C2.2, R2.2, R3.2, U1.1 (SIG_IN+)
unnamed: C4.2, R3.1, R5.1, R7.1, R8.2
unnamed: C2.1, X2.1
unnamed: C5.2, C7.2, R7.2, R9.1, R10.1, U1.8 (OSC_IN+)

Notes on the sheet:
750R
120mVpp
50R
480mVpp
850mVpp
(4/(2*4))²*3k=750Ohm
2*4T:4T


Board: 2 copper layers, 72.5 x 30.0 mm, 33 parts (0 on the bottom side), 21 nets.

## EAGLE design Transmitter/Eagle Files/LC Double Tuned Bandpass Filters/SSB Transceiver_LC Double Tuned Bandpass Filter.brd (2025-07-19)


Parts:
C1, C2: 33pF; C0805
C1L: 3pF; C0805
C1V, C2V: 30pF; VARIABLECAP-SMD
C2L: 8.2pF; C0805
C12: 1pF; C0805
L1, L2: 2.12uH; T50-6SMD
X1: SMA_IN; J502-ND-142-0711-821/826
X2: SMA_OUT; J502-ND-142-0711-821/826

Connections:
GND: C1.1, C1V.P$2 (A), C2.1, C2V.P$2 (A), L1.P$2 (2), L2.P$2 (2), X1.G@1 (2), X1.G@2 (2), X1.G@3 (2), X1.G@4 (2), X2.G@1 (2), X2.G@2 (2), X2.G@3 (2), X2.G@4 (2)
unnamed: C1.2, C1L.2, C1V.P$1 (E), C12.1, L1.P$1 (1)
unnamed: C2.2, C2L.2, C2V.P$1 (E), C12.2, L2.P$1 (1)
unnamed: C2L.1, X2.1
unnamed: C1L.1, X1.1

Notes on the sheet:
1.5k
180R
C1+C1V=55.3pF
C2+C2V=50.1pF
23T @ T50-6
f1 = 14MHz f2 = 14.4MHz BW = 400kHz
LC Double Tuned Double Terminated Bandpass Filter


Board: 2 copper layers, 69.5 x 18.0 mm, 11 parts (0 on the bottom side), 5 nets.

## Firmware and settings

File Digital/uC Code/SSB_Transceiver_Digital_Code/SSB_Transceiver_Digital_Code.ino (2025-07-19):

//This code is written by OE3SDE, Simon Dorrer!

//Define CPU-Clock-Speed (16MHz internal clock)
//#define F_CPU 16000000UL

//Define Baudrate for UART
//#define BAUD 9600UL

//Include Libraries
#include <avr/io.h>
#include <stdio.h>
#include <inttypes.h>
#include <avr/interrupt.h>

//Libs. for SH1106 OLED-Display
#include <Wire.h>
#include <U8g2lib.h>

//Libs. for Keypad
#include <Keypad.h>

//Libs. for Si5351 Breakout Board
#include <si5351.h>
//----------------------------------------------------------------------------

//Defines

//I/O Declaration
//#define TX        0     //PD0 / 0
//#define RX        1     //PD1 / 1
#define K_C1        2     //PD2 / 2
#define K_C2        3     //PD3 / 3
#define K_C3        4     //PD4 / 4
#define K_C4        5     //PD5 / 5
#define K_R1        6     //PD6 / 6
#define K_R2        7     //PD7 / 7
#define K_R3        8     //PB0 / 8
#define K_R4        9     //PB1 / 9
#define K_R5        10    //PB2 / 10
#define PTT_TXPWR   3     //PB3 / 11
#define PTT_TXRX    4     //PB4 / 12
#define PTT_IN      5     //PB5 / 13
#define TX_LED      0     //PC0 / 14 (A0) - PCINT5
#define DIR         1     //PC1 / 15 (A1)
#define STEP        2     //PC2 / 16 (A2)
#define POTI_F      3     //PC3 / 17 (A3)
//#define SDA       4     //PC4 / 18 (A4)
//#define SCK       5     //PC5 / 19 (A5)

//Defines for SH1106 Display
U8X8_SH1106_128X64_NONAME_HW_I2C SH1106(/* reset=*/ U8X8_PIN_NONE);

//Defines for Keypad
const byte ROWS = 5; // five rows
const byte COLS = 4; // four columns

char keys[ROWS][COLS] =
{
{'X','Y','#', '*' },       //X=F1, Y=F2
{'1','2','3', 'U' },       //U=up
{'4','5','6', 'D' },       //D=down
{'7','8','9', 'E' },       //E=Esc
{'L','0','R', 'O' }        //L=left, R=right, O=Ent
};

byte rowPins[ROWS] = {K_R5, K_R4, K_R3, K_R2, K_R1};
byte colPins[COLS] = {K_C1, K_C2, K_C3, K_C4};

Keypad keypad = Keypad(makeKeymap(keys), rowPins, colPins, ROWS, COLS);

char KEY[4] = {'1','5','0','5'};
char attempt[4] = {0,0,0,0};
int z=0;
int keystate = 0;                     // 0 = wrong key, 1 = right key

//Defines for Si5351 Breakout Board
Si5351 si5351;
//----------------------------------------------------------------------------

//Global variables
uint8_t firstLoop = 1;

//OLED Display variables
uint8_t updateDirOnDisplay = 1;
uint8_t updateDataOnDisplay = 1;
uint8_t updateFrequencyOnDisplay = 1;
uint8_t updateStepOnDisplay = 1;
uint8_t updatePTTOnDisplay = 1;
uint8_t USB = 1;                              //USB = 1... Upper Side Band is used!, USB = 0... Lower Side Band is used!

//UART variables
char readData = '0';                          //character for receiving data;

//ADC variables
int POTI_F_Value_new = 0;
int POTI_F_Value_old = 0;

//PTT variables
uint8_t PTT_IN_state = 2;                     //No state at the beginning, 1 = TX, 0 = RX

//Si5351 variables
uint8_t setSteps = 0;                         //set Frequency with Steps
uint8_t stepDir = 1;                          //1... up, 0... down;
uint8_t setPreciseFrequency = 0;              //set Frequency precise with Numpad

unsigned long f_cor = 63000;                  //63000
unsigned long f_step = 50;                    // set this to your wanted tuning rate in Hz.
unsigned long f_bandStart = 14000000;         // start of 20m (14MHz - 14.070MHz CW, 14.112MHz - 14.350MHz USB Voice)
unsigned long f_bandEnd = 14350000;           // end of 20m
unsigned long f_bandInit = 14200000;          // where to initially set the frequency
unsigned long f_BFOTX = 8998600;              // TX BFO frequency
unsigned long f_BFORX = 8999300;              // RX BFO frequency
unsigned long f_VFORX = f_bandInit - f_BFORX; // RX VFO frequency
unsigned long f_VFOTX = f_bandInit - f_BFOTX; // TX VFO frequency
unsigned long f_old = f_bandInit;
unsigned long f_new = f_bandInit;

//Stepper variables
unsigned long f_stepper = f_bandInit;
unsigned long f_perStep = 10000;         //Antenna changes XYZkHz per 1/16 step!
unsigned long f_difStepper = f_new - f_bandInit;
uint16_t motorSteps = 0;
//----------------------------------------------------------------------------

//Subprograms
//IO Subprograms
void IO_Init()                  //initialize IO
{
  //Define INPUTs
  DDRB &= ~(1 << PTT_IN);       //set PB5 (PTT_IN) as Input
  PORTB |= (1 << PTT_IN);       //activate Pull-Up-R at PB5 (PTT_IN)     
  
  DDRC &= ~(1 << POTI_F);       //set PA3 (POTI_F) as Input
  
  //Define OUTPUTs
  DDRB |= (1 << PTT_TXPWR);     //set PB3 (PTT_TXPWR) as Output
  //PORTB &= ~(1 << PTT_TXPWR);   //set PB3 (PTT_TXPWR) LOW at the beginning
  PORTB |= (1 << PTT_TXPWR);    //set PB3 (PTT_TXPWR) HIGH (inverted Logic) at the beginning --> PA off

  DDRB |= (1 << PTT_TXRX);      //set PB4 (PTT_TXRX) as Output
  PORTB &= ~(1 << PTT_TXRX);    //set PB4 (PTT_TXRX) LOW at the beginning

  DDRC |= (1 << TX_LED);        //set PA0 (TX_LED) as Output
  PORTC &= ~(1 << TX_LED);      //set PA0 (TX_LED) LOW at the beginning

  DDRC |= (1 << DIR);           //set PA1 (DIR) as Output
  PORTC &= ~(1 << DIR);         //set PA1 (DIR) LOW at the beginning

  DDRC |= (1 << STEP);          //set PA2 (STEP) as Output
  PORTC &= ~(1 << STEP);        //set PA2 (STEP) LOW at the beginning
}

void PCINT5_Init() //PCINT0-PCINT7
{
  PCICR |= (1 << PCIE0);    //Enable PCINT0-PCINT7
  PCMSK0 |= (1 << PCINT5);  //Enable PCINT5 --> PB5
}

//Timer1 OCR1A Interrupt
void Timer1_OCR1A_Init()
{
  //Control Registers
  TCCR1A = 0;
  TCCR1B = 0;
  TCCR1C = 0;
  
  // set CTC mode
  //TCCR1A |= (1 << WGM10);
  //TCCR1A |= (1 << WGM11);
  TCCR1B |= (1 << WGM12);
  
  // Set Prescaler 102
  TCCR1B |= (1 << CS10);
  //TCCR1B |= (1 << CS11);
  TCCR1B |= (1 << CS12);
  
  // initialize compare value (INT. every 200ms)
  OCR1A = 3125;
  
  // enable timer compare interrupt
  TIMSK1 |= (1 << OCIE1A);
}

//ADC Subprograms
void ADC_Init(void)
{
  //ADC Setup
  //Set Reference Voltage (VCC = VREF)
  ADMUX &= ~(1<<REFS1);
  ADMUX |= (1<<REFS0);
  
  //Prescaler --> 128 (50kHz - 200kHz)
  ADCSRA |= (1<<ADPS0);
  ADCSRA |= (1<<ADPS1);
  ADCSRA |= (1<<ADPS2);
  
  ADCSRA |= (1<<ADEN); //Enable ADC
}
int ReadAnalogValue(int Pin)            // Read ADC Value
{
  ADMUX = (1<<REFS0) | (Pin & 0x0f);    //select input and ref
  ADCSRA |= (1<<ADSC);                  //Start ADC conclusion
  while (ADCSRA & (1<<ADSC)){}          //wait until ADC is ready
  return ADC;                           //return the ADC value
}

//UART Subprograms
void UART_Init()                  //initialize UART
{
  //initial state
  UCSR0A = 0;
  UCSR0B = 0;
  UCSR0C = 0;
  
  //Set Baudrate --> UBRR0_VALUE = ((F_CPU/(16*BAUD)) - 1) --> Baudrate = 9600
  UBRR0H = 0x00;
  UBRR0L = 103;                 //Baudrate calculation on page 173 of ATmega328 datasheet
    
  //UCSR0B Register
  //Enable USART RX-Interrupt
  UCSR0B |= (1 << RXCIE0);
    
  //Enable USART Receive and Transmit
  UCSR0B |= (1 << TXEN0);
  UCSR0B |= (1 << RXEN0);
    
  //UCSR0A Register
  //Asynchronous Mode, Parity Disabled, 8 Bit character size, Transmitted Data Changed (rising edge), Received Data Sampled (falling edge)
  UCSR0C |= (1 << UCSZ00);
  UCSR0C |= (1 << UCSZ01);
}
int UART_putchar(char c, FILE *stream)
{
  while(!((UCSR0A) & (1 << (UDRE0))));      //loop until bit UDRE0 is set in register UCSR0A (If UDRE0 is one, the buffer is empty, and therefore ready to be written.)
  UDR0 = c;
  return(0);
}
int UART_getchar(FILE *stream)
{
  while(!((UCSR0A) & (1 << (RXC0))));       //loop until bit RXC0 is set in register UCSR0A (If RXC0 is one, the receiver buffer contains unread data.)
  return(UDR0);
}

//SH1106 OLED-Display Subprograms
void SH1106_setMenu(unsigned long f, unsigned long fstep, char BT)
{
  SH1106.clear();
  SH1106.drawString(1, 1, "Frequency: ");
  if(stepDir == 1)
  {
    SH1106.drawString(12, 1, "UP");
  }
  else if(stepDir == 0)
  {
    SH1106.drawString(12, 1, "DOWN");
  }

  SH1106.setCursor(1, 3);
  SH1106.print(f);  
  SH1106.drawString(9, 3, "Hz");

  SH1106.drawString(13, 3, "20m");
  
  SH1106.drawString(1, 5, "f-Step:  ");
  SH1106.setCursor(9, 5);
  SH1106.print(fstep);  
  SH1106.drawString(11, 5, "Hz");
  
  SH1106.drawString(1, 7, "BT:");
  SH1106.setCursor(5, 7);
  SH1106.print(BT); 

  if(USB == 1)
  {
    SH1106.drawString(8, 7, "USB");
  }
  else
  {
    SH1106.drawString(8, 7, "LSB"); 
  }

  if(PTT_IN_state == 1)
  {
    SH1106.drawString(13, 7, "TX");
  }
  else if(PTT_IN_state == 0 || PTT_IN_state == 2)
  {
    SH1106.drawString(13, 7, "RX");
  }
}

void SH1106_update(unsigned long f, unsigned long fstep, char BT)
{
  if(updateDirOnDisplay == 1)
  {
    if(stepDir == 1)
    {
      SH1106.drawString(12, 1, "     ");
      SH1106.drawString(12, 1, "UP");
    }
    else if(stepDir == 0)
    {
      SH1106.drawString(12, 1, "     ");
      SH1106.drawString(12, 1, "DOWN");
    } 
    updateDirOnDisplay = 0;
  }

  if(updateFrequencyOnDisplay == 1 && setSteps == 0)
  {
    SH1106.drawString(1, 3, "        ");
    SH1106.drawString(8, 5, " ");
    SH1106.setCursor(1, 3);
    SH1106.print(f);  
    SH1106.drawString(11, 3, "-");
    updateFrequencyOnDisplay = 0;
  }

  if(updateStepOnDisplay == 1 && setSteps == 1)
  {
    SH1106.drawString(8, 5, "-");
    SH1106.drawString(11, 3, " ");
    SH1106.drawString(9, 5, "       ");
    SH1106.setCursor(9, 5);
    SH1106.print(fstep);
    switch(fstep)
    {
      case 50:
        SH1106.drawString(11, 5, "Hz");
      break;
      case 100:
        SH1106.drawString(12, 5, "Hz");
      break;
      case 500:
        SH1106.drawString(12, 5, "Hz");
      break;
      case 1000:
        SH1106.drawString(13, 5, "Hz");
      break;
        case 5000:
        SH1106.drawString(13, 5, "Hz");
      break;
        case 10000:
        SH1106.drawString(14, 5, "Hz");
      break;
      default:
      break;
    }
    updateStepOnDisplay = 0;
  }

  if(updateDataOnDisplay == 1)
  {
    SH1106.drawString(7, 7, " ");
    SH1106.setCursor(5, 7);
    SH1106.print(BT); 
    updateDataOnDisplay = 0;
  }
  if(updatePTTOnDisplay == 1)
  {
    if(PTT_IN_state == 1)
    {
      SH1106.drawString(13, 7, "TX");
    }
    else if(PTT_IN_state == 0)
    {
      SH1106.drawString(13, 7, "RX");
    }
    updatePTTOnDisplay = 0;
  }
}
    
//Keypad Subprogams
void noPW()
{ 
  delay(1000);
  SH1106.clear();
  SH1106.drawString(2, 4, "KEY ACCEPTED!");
  printf("KEY ACCEPTED!\n\r");
  delay(2000);
  //ClearDisplay();
  SH1106.clear();
  keystate = 1;
}
void checkKEY()
{
  int correct=0;
  int i;
  for ( i = 0; i < 4 ; i++ )
  {
    if (attempt[i] == KEY[i])
    {
       correct++;
    }
  }
  if (correct == 4)
  {
    SH1106.clear();
    SH1106.drawString(2, 4, "KEY ACCEPTED!");
    printf("KEY ACCEPTED!\n\r");
    delay(2000);
    SH1106.clear();
    //ClearDisplay();
    keystate = 1;
    firstLoop = 1;
  }
  else
  {
    SH1106.clear();
    SH1106.drawString(2, 4, "KEY REJECTED!");
    printf("KEY REJECTED!\n\r");
    delay(2000);
    
    SH1106.clear();
    SH1106.drawString(0, 3, "Enter Password:");
    keystate = 0;
  }
  for (int zz = 0; zz < 4; zz++) // clear previous key input
  {
    attempt[zz] = 0;
  }
}
void readKeypad()
{
  char key = keypad.getKey();
  //printf("%c \n\r", key);
   
  if (key != NO_KEY)
  {
    if(keystate == 0)
    {
      switch(key)
      {
      case '*':
        z = 0;
        SH1106.drawString(2, 5, ".");
      break;
      case '#':
        if(z == 4)
        {
          SH1106.drawString(2, 5, ". * * * * .");
        }
        SH1106.drawString(2, 5, ".");
        delay(100); // added debounce
        checkKEY();
      break;
      case 'E':
        SH1106.drawString(2, 5, ". * * * * .");
        noPW();
      break;
      default:
        attempt[z] = key;
        z++;
        switch(z)
        {
          case 1:
            SH1106.drawString(2, 5, ". *");
          break;
          case 2:
            SH1106.drawString(2, 5, ". * *");
          break;
          case 3:
            SH1106.drawString(2, 5, ". * * *");
          break;
          case 4:
            SH1106.drawString(2, 5, ". * * * *");
          break;
        }    
      }
    }
    
    if(keystate == 1)
    {
      switch(key)
      {
      case 'O':
        f_old = f_new;
      break;
      case 'U':
        stepDir = 1;
        updateDirOnDisplay = 1;
      break;
      case 'D':
        stepDir = 0;
        updateDirOnDisplay = 1;
      break;
      case 'X':
        if(setSteps == 1)
        {
          setSteps = 0;
        }
        else if(setSteps == 0)
        {
          setSteps = 1;
        }
        setPreciseFrequency = 0;
      break;
      case 'Y':
        setPreciseFrequency = 1;
      break;
      /*case '*':
      break;
      case '#':
      break;*/
      case 'E':
        f_new = f_bandInit;
        f_old = f_bandInit;
      break;
      default:
        printf("Default!");
      }
    }
  }
}

//Si5351 + Stepper Driver Subprograms
void setFrequencySteps(int POTI_F_Value)
{
  if(setSteps == 1)
  {
    f_old = f_new;
    if(POTI_F_Value >= 0 && POTI_F_Value < 180)
    {
      f_step = 50;
      printf("Step: 50Hz");
    }
    else if(POTI_F_Value >= 180 && POTI_F_Value < 360)
    {
      f_step = 100;
      printf("Step: 100Hz");
    }
    else if(POTI_F_Value >= 360 && POTI_F_Value < 540)
    {
      f_step = 500;
      printf("Step: 500Hz");
    }
    else if(POTI_F_Value >= 540 && POTI_F_Value < 720)
    {
      f_step = 1000;
      printf("Step: 1kHz");
    }
    else if(POTI_F_Value >= 720 && POTI_F_Value < 900)
    {
      f_step = 5000;
      printf("Step: 5kHz");
    }
    else if(POTI_F_Value >= 900 && POTI_F_Value < 1024)
    {
      f_step = 10000;
      printf("Step: 10kHz");
    }
  }
  else if(setSteps == 0)
  {
    if(stepDir == 1)
    {
      f_new = f_old + (f_step*(POTI_F_Value/20));
    }
    else if(stepDir == 0)
    {
      f_new = f_old - (f_step*(POTI_F_Value/20));
    }
    
    if(f_new < f_bandStart)
    {
      f_new = f_bandStart;
    }
    if(f_new > f_bandEnd)
    {
      f_new = f_bandEnd;
    }
    /*printf("f_step: %lu Hz \n\r", f_step);
    printf("f_old: %lu Hz \n\r", f_old);
    printf("f_VFORX: %lu Hz \n\r", f_new-f_BFORX);
    printf("f_VFOTX: %lu Hz \n\r", f_new-f_BFOTX);
    printf("f_new: %lu Hz \n\r", f_new);*/
  }
}

void setStepperDriver(unsigned long f)  //Driver operates in "sixteenth step mode"!
{
  //Example: f = 14MHz, f_stepper = 14.2MHz --> f_difStepper = 200kHz, --> motorSteps = 20 @ f_perStep = 10kHz
  if(f_stepper > f)
  {
    PORTC |= (1 << DIR);            //set PA1 (DIR) HIGH (clockwise)
    f_difStepper = f_stepper - f;
  }
  else if(f_stepper < f)
  {
    PORTC &= ~(1 << DIR);           //set PA1 (DIR) LOW (counter clockwise)
    f_difStepper = f - f_stepper;
  }

  motorSteps = f_difStepper / f_perStep;

  /*printf("f: %lu Hz \n\r", f);
  printf("f_stepper: %lu Hz \n\r", f_stepper);
  printf("f_difStepper: %lu Hz \n\r", f_difStepper);
  printf("f_stepper: %lu Hz \n\r", f_perStep);
  printf("motorSteps: %d \n\r", motorSteps);*/
  
  for(int m = 0; m < motorSteps; m++) 
  { 
    PORTC |= (1 << STEP);        //set PA2 (STEP) HIGH
    delayMicroseconds(250);  
    PORTC &= ~(1 << STEP);        //set PA2 (STEP) LOW
    delayMicroseconds(250); 
  }
  
  f_stepper = f;
  f_difStepper = 0;
}

void setFrequency(unsigned long f)
{
  //configure Stepper Driver (Capacitor on Magnetic Loop Antenna)
  setStepperDriver(f);
  
  //configure Si5351 CLKs
  f_VFORX = f - f_BFORX;
  f_VFOTX = f - f_BFOTX;

  if(PTT_IN_state == 1) //TX
  {
    si5351.set_clock_pwr(SI5351_CLK1, 0);
    si5351.set_clock_pwr(SI5351_CLK0, 1);
    si5351.drive_strength(SI5351_CLK0, SI5351_DRIVE_2MA);   // 280mV amplitude for SA612
    si5351.set_freq((f_VFOTX * 100ULL), SI5351_CLK0);
    si5351.set_freq((f_BFOTX * 100ULL), SI5351_CLK2);
  }
  else //RX
  {
    si5351.set_clock_pwr(SI5351_CLK0, 0);
    si5351.set_clock_pwr(SI5351_CLK1, 1);
    si5351.drive_strength(SI5351_CLK1, SI5351_DRIVE_2MA);   // 280mV amplitude for SA612
    si5351.set_freq((f_VFORX * 100ULL), SI5351_CLK1);
    si5351.set_freq((f_BFORX * 100ULL), SI5351_CLK2);
  }
  
}

//PTT Subprograms
void setPTT()
{
  if(PTT_IN_state == 1)
  {
    PORTC |= (1 << TX_LED);           //set PA0 (TX_LED) HIGH
    PORTB |= (1 << PTT_TXRX);         //set PB4 (PTT_TXRX) HIGH (RX to GND, TX to ANT.)
    delay(500);                       //wait 100ms (let TXRX Relais settle)
    //PORTB |= (1 << PTT_TXPWR);      //set PB3 (PTT_TXPWR) HIGH --> turn on PA
    PORTB &= ~(1 << PTT_TXPWR);       //set PB3 (PTT_TXPWR) LOW (inverted Logic) --> turn on PA
  }
  else if(PTT_IN_state == 0)
  {
    //PORTB &= ~(1 << PTT_TXPWR);     //set PB3 (PTT_TXPWR) LOW --> turn off PA
    PORTB |= (1 << PTT_TXPWR);        //set PB3 (PTT_TXPWR) HIGH (inverted Logic) --> turn off PA
    delay(500);                       //wait 100ms (let TX_PWR Relais settle)
    PORTB &= ~(1 << PTT_TXRX);        //set PB4 (PTT_TXRX) LOW (RX to ANT., TX to GND)
    PORTC &= ~(1 << TX_LED);          //set PA0 (TX_LED) LOW
  }
}
//----------------------------------------------------------------------------

//Setup (Initialize hardware)
void setup()
{
  //Init IO
  IO_Init();

  //Init Timer1
  Timer1_OCR1A_Init();

  //Init PCINT5
  PCINT5_Init();
  
  //Init UART
  UART_Init();
  fdevopen(UART_putchar, UART_getchar);          //define printf
  
  //Init ADC
  ADC_Init();

  //Init I2C
  Wire.begin();
  
  //enable global interrupts
  sei();

  //Init SH1106 OLED-Display
  SH1106.begin();
  SH1106.clear();
  SH1106.setFont(u8x8_font_amstrad_cpc_extended_r);
  
  //Set start Text
  SH1106.drawString(1, 1, "14MHz SSB TRX");
  SH1106.drawString(1, 4, "by OE3SDE");
  SH1106.drawString(1, 7, "Simon Dorrer");
  printf("14MHz SSB TRX\n\r");
  printf("by OE3SDE\n\r");
  printf("Simon Dorrer\n\r");

  delay(2000);
  
  //Init Si5351 Breakout Board
  //https://github.com/etherkit/Si5351Arduino
  bool i2c_found = si5351.init(SI5351_CRYSTAL_LOAD_8PF, 0, 0);
  if(i2c_found == false)
  {
    SH1106.clear();
    SH1106.drawString(3, 4, "No Si5351!");
    printf("No Si5351!\n\r");
  }
  else
  {
    printf("Si5351 found!\n\r");

    //Set Up Si5351 Settings
    si5351.set_correction(f_cor, SI5351_PLL_INPUT_XO);      // Set to specific Si5351 calibration number
    si5351.set_pll(SI5351_PLL_FIXED, SI5351_PLLA);
    
    // 8mA=880mV, 6mA=680mV, 4mA=480mV, 2mA=280mV
    si5351.drive_strength(SI5351_CLK0, SI5351_DRIVE_2MA);   // 280mV amplitude for SA612
    si5351.drive_strength(SI5351_CLK1, SI5351_DRIVE_2MA);   // 280mV amplitude for SA612
    si5351.drive_strength(SI5351_CLK2, SI5351_DRIVE_4MA);   // 480mV amplitude for MC1496

    //Query a status update and wait a bit to let the Si5351 populate the status flags correctly.
    si5351.update_status();
    
    //Set Password
    delay(2000);
    SH1106.clear();
    SH1106.drawString(0, 3, "Enter Password:");
    printf("Enter Password!\n\r");
  }
}
//----------------------------------------------------------------------------

//Loop
void loop()
{
  if(keystate == 0)
  {
    readKeypad();
  }
  else if(keystate == 1)
  {
    if(firstLoop == 1)
    {
      SH1106_setMenu(f_bandInit, f_step, readData);
    }
    else
    {
      SH1106_update(f_new, f_step, readData);
      setPTT();
      setFrequency(f_new);
    }
    firstLoop = 0;
  }
  delay(100);
}
//----------------------------------------------------------------------------

//ISP (Interrupt Service Routine) 
//Timer1 COMPA ISR
ISR(TIMER1_COMPA_vect)
{
  if(keystate == 1)
  {
    readKeypad();
    
    POTI_F_Value_new = ReadAnalogValue(POTI_F);
    if((POTI_F_Value_new >= (POTI_F_Value_old + 5)) || (POTI_F_Value_new <= (POTI_F_Value_old - 5)))
    {
      updateFrequencyOnDisplay = 1;
      updateStepOnDisplay = 1;
    }
    POTI_F_Value_old = POTI_F_Value_new;
    
    setFrequencySteps(POTI_F_Value_new);
  }
}

//UART receive ISR
ISR(USART_RX_vect)                      //If data from PC is received completely of UART interface, an interrupt occurs.
{
  updateDataOnDisplay = 1;
  if(keystate == 1)
  {
    readData = UDR0;
   
    switch(readData)                    //evaluate the received data
    {
      case 'a':
        printf("a\n\r");
      break;
      case 'b':
        printf("b\n\r");
      break;
      default:
        //printf("Keine richtige Anweisung!\n\r");
      break;
    }
  }
  else
  {
    printf("No Password is entered!\n\r");
  }
}

//PTT
//PCINT0-7 ISR
ISR(PCINT0_vect)
{
  if(keystate == 1)
  {
    updatePTTOnDisplay = 1;
    if(!(PINB & (1 << PTT_IN)))         //PTT_IN changed to LOW
    {
      printf("PTT_IN_LOW\n\r"); 
      PTT_IN_state = 1;
    }
    else if (PINB & (1 << PTT_IN))      //PTT_IN changed to HIGH
    {
      printf("PTT_IN_HIGH\n\r");
      PTT_IN_state = 0;
    }
  }
}
//----------------------------------------------------------------------------

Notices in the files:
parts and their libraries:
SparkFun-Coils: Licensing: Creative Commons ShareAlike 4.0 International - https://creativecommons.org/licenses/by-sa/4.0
